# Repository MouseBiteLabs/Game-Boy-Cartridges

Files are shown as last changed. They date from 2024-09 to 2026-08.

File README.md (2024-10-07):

# Game Boy Cartridge Circuit Boards

This is a repository listing all of my Game Boy game circuit board variants.

## Game Boy Board Links

| **Board Name** | **Board Number** | **Max ROM Size** | **Max RAM Size**  | **Multicart Support?** | **Memory Family Used** |
|---|---|---|---|---|---|
| MBC1 (Type B) | GB-4DV4S-01B | 4 MB | 32 KB | No | Type B (29F016, 29F032, 29F033) |
| MBC3 (Type B) | GB-4KV4S-01B | 4 MB | 32 KB | No | Type B (29F016, 29F032, 29F033) |
| MBC5 (Type B) | GB-4AV8S-01B | 4 MB | 128 KB | No | Type B (29F016, 29F032, 29F033) |
| MBC3 Multicart | GB-4KV8S-01B | 4 MB (2x 2 MB, 4x 1MB) | 128 KB (4x 32 KB) | Yes | Type B (29F032, 29F033) |
| MBC5 Multicart | GB-4AV8S-01B | 4 MB (2x 2 MB, 4x 1MB) | 128 KB (4x 32 KB) | Yes | Type B (29F032, 29F033) |
| MBC1 (Type A) | GB-2DV4S-01A | 2 MB | 32 KB | No | Type A (M29F160) |
| MBC3 (Type A) | GB-2KV4S-01A | 2 MB | 32 KB | No | Type A (M29F160) |
| MBC5 (Type A) | GB-2AV8S-01A | 2 MB | 128 KB | No | Type A (M29F160) |
| MBC1 (Type A, FRAM)  | GB-2DF4S-01A | 2 MB | 32 KB | No | Type A (M29F160) |
| MBC3 (Type A, FRAM)  | GB-2KF4S-01A | 2 MB | 32 KB | No | Type A (M29F160) |
| MBC5 (Type A, FRAM)  | GB-2AF4S-01A | 2 MB | 32 KB | No | Type A (M29F160) |

## Naming Convention

| GB | \- | 2 | A | V | 4 | S | \- | 01 | A |
| --- | -- | --- | --- | --- | --- | --- | -- | --- | --- |
| Game Boy | | Max ROM Size (MB) | Mapper Chip | SRAM or FRAM?  | Max RAM Size | Multicart Support | | Revision | Memory Family |
| | | 1 | N = None | X = None | 0 = None | S = Single game | | | A = New EEPROM (M29F160) |
| | | 2 | D = MBC1 | V = SRAM | 1 = 2 KB | D = Multicart (2x, split max ROM/RAM space)  | | | B = NOS EEPROM (29F016, 29F032, 29F033) |
| | | 4 | K = MBC3 | F = FRAM | 2 = 8 KB | Q = Multicart (4x, split max ROM/RAM space)  | | | |
| | | 6 | A = MBC5 | | 4 = 32 KB | | | | |
| | | 8 | | | 8 = 128 KB | | | | |

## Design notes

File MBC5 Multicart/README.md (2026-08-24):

# Game Boy MBC5 Multicart

This is a slightly updated design of my original flashable MBC5-based multicart for the Game Boy. You can make a 2-in-1 or 4-in-1 cartridge, that changes games based on a button press or power cycling the Game Boy. With this board you can also make a single game, but with the addition of a pressable reset button on the cartridge.

**This MBC5 cartridge uses new old stock 29F033 EEPROM chips and battery-backed SRAM.**

The features are as follows:

- Able to make a cartridge with either 2x 2 MB games or 4x 1 MB games
- Adds a pressable button to the cartridge (no shell cutting required)
  - The button can be configured to cycle games on the cart, reset the console, or both
- Configurable to have separate save data for each game, or to share the same save data across multiple games
- Fully compatible with the <a href="https://www.gbxcart.com/">GBxCart RW</a> so you can transfer games and save files to and from the board

Some examples of fun cartridges you can make with this board are:
- A single Pokemon game that has a reset button
- Both Pokemon Red and Blue with separate saves
- Both Pokemon Red and Blue with *the same* save (save files are compatible between versions!)
- Both Pokemon Red and Blue with *the same* save that can switch between versions *during gameplay without resetting* (hotswap!)
- A single copy of Powerpuff Girls with two separate save files



All gerbers and source files can be found in this repo, as this project is fully open source.

## Tutorial Video

This is a video tutorial for the MBC3 multicart specifically, but the process is nearly identical.

Multicart Video Tutorial (http://www.youtube.com/watch?v=DJ7rJUZhDuM "Game Boy Multicart Tutorial (Pokemon Gold and Silver)")

## Important Things Before You Start

1) To use this board, you need to have an original Game Boy game that uses an MBC5 mapper chip. <a href="https://catskull.net/gb-rom-database/">You can find a list of games and their mappers here</a>. Use the search function. Please note the RAM is in bytes, not bits. Since SRAM in this repo is defined in bits, you need to convert by multiplying the number of bytes by 8.
2) You will need to remove the MBC5 from your donor cartridge for use on this board. This will require a hot air rework station or a hot plate. There's a list below of other parts you can re-use from the donor cartridge.
3) When soldering parts on, it's a good idea to put kapton tape or otherwise cover the bottom cartridge edge. You do not want to get solder on the cartridge contacts.
4) I am not responsible for any damage you do to your self or your property. Attempt this project at your own risk.
5) I do not guarantee design compatibility. You may encounter issues with certain games. There is also a chance I have made an error in the design or the BOM - if this is the case, I will do everything I can to address the problem as quickly as possible.
6) If you are using this board to make games other than for personal use, you must have permission from the originator to use and distribute any ROM images or other related material. You are responsible for making sure you adhere to any license requirements.

DO NOT use my circuit boards for profiting from stolen work - this especially includes homebrew content, ROM hacks, and using fan-made labels without permission from the originator. **Support original creators!**

## Board Characteristics and Order Information

The zipped folder contains all the gerber files for this board. The following options **must** be chosen when ordering boards for yourself.

- Thickness: 0.8mm
- Surface Finish: ENIG
- Gold Fingers: Yes, 30° chamfer

You can use the zipped folder at any board fabricator you like. You may also buy the board from PCBWay using this link (disclosure: I receive 10% of the sale value to go twoards future PCB orders of my own):

<a href="https://www.pcbway.com/project/shareproject/Game_Boy_MBC5_Multicart_Updated_3609010b.html">PCB from PCBWay</a>

<a href="https://oshpark.com/shared_projects/IAKoKwEI">The board is also listed on OSH Park as well.</a> **Be sure to get them in 0.8mm thickness if you order from here.**

### Purchase from Etsy

I also offer the board on Etsy, if you would rather purchase through there - click the banner to be redirected.

<a href="https://mousebitelabs.etsy.com/listing/1880161628/game-boy-multicart-pcb-mbc5-v20">PCB from Etsy</a> 

## Required Equipment

The EEPROM on the board needs to be programmed somehow. There are a few options for doing this:

1) <a href="https://www.gbxcart.com/">**GBxCart**</a>. This is a perfect option if you want an easy way to make Game Boy cartridges without a lot of extra effort. This is a standalone flasher that plugs into your computer via USB. The cartridge circuit board is fully compatible with it, and it makes reflashing games extremely easy using <a href="https://github.com/lesserkuma/FlashGBX">lesserkuma's FlashGBX software</a>.
2) At the lowest level, you can buy an EEPROM programmer with a TSOP chip programming adapter. The downside to this method is that you have to desolder the chip every time you want to program it. The <a href="https://flashcatusb.com/">FlashcatUSB</a> is one popular option in retro spaces, but I use the <a href="https://xgecu.myshopify.com/products/xgecu-new-t48-tl866-3gprogrammer-v12-01-support-28000-ics-for-spi-nor-nand-flash-emmc-bga153-162-169-100-221-tsop-sop-plcc">T48 programmer</a> with the <a href="https://xgecu.myshopify.com/products/100-original-xgecu-adp_f48_ex-1-tsop48-special-adapter-for-nor-flash-only-use-on-t48-tl866-3g-programmer">TSOP48 adapter</a>.

You may also be able to use the <a href="https://github.com/sanni/cartreader">**OSCR**</a> by sanni, but in order to do that you will need to prepare a single ROM file with both games and program it to the first game slot. Or, you will need to add a programming routine into the Arduino code to write a file without erasing the chip first. Consider yourself on your own for this until an addition to the OSCR repository is made to address this.

### How to Program the Cartridges

When using the GBxCart to program multiple games to the cartridge, it's recommended to turn SW2A and SW2B (detailed below) to the OFF position. To change ROM/RAM banks to program, simply press the SW1 tactile button between programming steps. Using FlashGBX's "Refresh" button should show that the game information on the left of the screen changes after pressing the button.

If you're programming the flash chip separate from the board, you'll need to concatenate all the ROM files together into one large 4 MB file to program the chip with.

<a href="https://github.com/MouseBiteLabs/Game-Boy-Cartridges/wiki">Also, you can check out the wiki for more information.</a>

## Battery Safety

When assembling a board, I recommend populating all the parts *except* the battery, and getting it to run initially without it. This is to make it easier to fix any solder connections that might need fixing, without having to worry about getting the battery hot. And if you need to rework anything near the battery after you've put it on the board, be safe and remove it before putting a hot soldering iron next to it.

And this should go without saying, but if you're assembling these boards with a hot plate or hot air, *do not* solder the battery on this way. You should use an iron, and keep heat off of the battery as much as possible. 

(Also check polarity!)

## Board Configurations

There's a lot to cover here. There are four separate switches to configure, and two different sizes of SRAM to pick from.

*Note that you can simply solder bridges from the middle pads of the switches to the left or right to the "ON" or "OFF" positions, instead of installing an actual switch.*

### SRAM Size Selection

There are two sizes of SRAM you can use, and the type you use will dictate how your save data is stored on the cartridge and if it's shared between games or not.

- If you use a 1 Mbit SRAM (like the AS6C1008), then each game you put on the cartridge will have its own separate save files. If you program multiple copies of the same game, then you can effectively have multiple save files on the same cart. Easy example is Pokemon games - they only let you have one save file, but if you put Pokemon Red on the multicart four times, then that gives you four separate save files!
- If you use a 256 Kbit SRAM (like the AS6C62256) then all the games you put on the cartridge will *share* the same RAM space.  This feature is probably only useful for Pokemon games. As an example: this means that if you made a cart that has Pokemon Red and Blue on it, you would play both versions with the same save data, as save data between the two games are compatible with each other.

### Game Cycling Mode Switch (SW2)

SW2, split into two separate switches SW2A (top half) and SW2B (bottom half), controls how you change games on the cartridge. The following table describes the different settings:

| Mode | SW2A (Bottom) | SW2B (Top) | Game change with reset? | Game change with button press? | Does the button reset? |
| ---- | --- | --- | --- | --- | --- |
| 1 | OFF | OFF | No | Yes | Yes |
| 2 | OFF | ON | No | Yes | No |
| 3 | ON | OFF | Yes | Yes | Yes |
| 4 | ON | ON | Yes | No | No |

*Note: Mode 4 does not give function to the push button at all.*

The "game change" method in this table describes how you advance down the "game" columns described in the table for SW3.

### Game and Save Data Configuration Switch (SW3)

SW3, split into two separate switches SW3A (bottom half) and SW3B (top half), controls the order in which the ROM banks (the games) and the RAM banks (the save data) cycle. This table assumes you are using a 1 Mbit SRAM chip. If you are using a 256 Kbit SRAM, then every entry in the "RAM Banks" column can be described as "1x 256 Kbit", and all the "Game" columns will share that single RAM bank.

Please note that SW3A and SW3B are *different* than the SW3A and SW3B on the MBC3 Multicart PCB.

| Mode | SW3A (Top) | SW3B (Bottom) | ROM Banks  | RAM Banks | Game 1 | Game 2 | Game 3 | Game 4 |
| ---- | ---- | ---- | --- | --- | --- | --- | --- | --- |
| A | ON | OFF  | 2x 2 MB | 4x 256 Kbit | ROM1, RAM1 | ROM1, RAM2 | ROM2, RAM3 | ROM2, RAM4 |
| B | OFF  | OFF  | 4x 1 MB | 4x 256 Kbit | ROM1, RAM1 | ROM2, RAM2 | ROM3, RAM3 | ROM4, RAM4 |
| C | ON | ON | 2x 2 MB | 2x 256 Kbit | ROM1, RAM1 | ROM2, RAM2 | | |
| D | OFF  | ON | 2x 1 MB | 2x 256 Kbit | ROM1, RAM1 | ROM2, RAM2 | | |

*Note: Mode D is the same as Mode C, but with restricted space for the ROM, so there's no practical use for Mode D.*

### Game Mode Examples

Here's a list of example cartridges you can make with these settings:
1) Pokemon Red, Blue, Yellow, and Green on one cartridge with separate save files that changes only via pressing the button, which also resets the game: **Mode 1B** with 1 Mbit SRAM
2) Pokemon Red and Blue with separate save files that changes by pressing the button *or* cycling power on the Game Boy: **Mode 3C** with 1 Mbit SRAM
3) Pokemon Red and Blue with the same save file that hotswaps when you press the button on the cartridge (changing games during gameplay): **Mode 2C** with 256 Kbit SRAM

## Test Points and Final Checkout

On the back of the board are five test points. Here's where they are connected:

- TP1: SRAM supply voltage
- TP2: Battery voltage (after R1)
- TP3: Battery voltage (positive terminal of battery)
- TP4: Ground
- TP5: VCC input voltage

After you assemble your game, you should measure the current out of the battery. But first, you should program it with the GBxCart, or if you programmed the EEPROM separately, put it into a Game Boy and cycle power once. Then, flip the PCB upside down on a non-conductive surface (not your leg), and set your multimeter in DC millivolts (or volts). Put the positive probe on TP3 and the negative probe on TP2. If you used a 10kΩ for R1, as indicated in the BOM, you should read a voltage in the single or tens of millivolts. If you have something much higher, especially voltages above 100mV, then you likely have an issue or short circuit on the board somewhere.

**Note: You need to power up the game at least once before battery currents will make sense - the battery management ICs can start up in an unknown state before applying main power to the board.**

To estimate battery life, see <a href="https://github.com/MouseBiteLabs/Game-Boy-MBC5-Cartridge/tree/main/Technical#estimating-battery-life">this section in the Technical Design Document of my first MBC5 design</a>, or for more in-depth analysis, <a href="https://hackaday.io/project/11864-tritiled/log/72554-determining-maximum-runtime-176-to-202-years-cr2032">this Hackaday post</a>.

### Battery Size Considerations

The coin cells commonly used on Game Boy carts in order of increasing size are CR2016, CR2025, and CR2032. The CR2032 is the thickest, but yields the longest battery life.

Batteries that are as large as CR2032 will fit inside the shell, *however*, due to the thickness of the CR2032, using one makes it so the shell cannot be pressed down very easily. This makes the button inside the shell difficult to press reliably. For this reason, I recommend using the CR2025. If you want to use a CR2032 for a bit longer battery life, you should only expect to make a cart that changes games via power cycling only (Modes 3 or 4).

I haven't tested it, but I believe using battery holders instead of pre-tabbed batteries will similarly cause issues with trying to press the button in the middle of the cartridge.

## Board Fitment

The shape of this board was originally meant to mimic original Game Boy circuit boards as closely as possible. Unfortunately, when placed in some aftermarket Game Boy cartridge shells (like those from Cloud Game Store), the circuit board has a lot of freedom to rotate around the main screw hole in the bottom-middle of the cartridge. This can cause misalignment when you put it in a Game Boy, which can cause a game to either not load properly (garbled Game Boy logo) or shut off the Game Boy because of a short circuit. This isn't *dangerous* or anything, just annoying.

In order to make the boards fit nicer in any kind of shell, I added extended tabs of circuit board material to the edges of the cartridges to keep it from rotating too much in shells, which was suggested to me by <a href="https://github.com/orangeglo">orangeglo</a>! (Thanks!)

If you're having trouble fitting the circuit board into a shell, because the tabs interfere with the cart edges, you can safely sand or trim them down as there is no copper within the tabs themselves. The only shell that appears to require any kind of trimming are Kitsch-Bent shells.

## Bill of Materials (BOM)

| Reference Designators | Value/Part Number | Package | Description | Source |
| --- | --- | --- | --- | --- |
| B1 | CR2025, CR2016, CR2032*| See note above | Backup Battery | [https://mou.sr/3PLccol](https://mou.sr/3PLccol) |
| C1 | 0.1uF | 0603 | Capacitor (MLCC) | [https://mou.sr/3ENc15O](https://mou.sr/3ENc15O) |
| C4 | 0.1uF | 0603 | Capacitor (MLCC) | [https://mou.sr/3ENc15O](https://mou.sr/3ENc15O) |
| C5 | 0.1uF | 0603 | Capacitor (MLCC) | [https://mou.sr/3ENc15O](https://mou.sr/3ENc15O) |
| C6 | 10uF | 0603 | Capacitor (MLCC) | [https://mou.sr/3mZtSkF](https://mou.sr/3mZtSkF) |
| C7 | 0.1uF | 0603 | Capacitor (MLCC) | [https://mou.sr/3ENc15O](https://mou.sr/3ENc15O) |
| C8 | 0.01uF | 0603 | Capacitor (MLCC) | [https://mou.sr/3AsRwK1](https://mou.sr/3AsRwK1) |
| C12 | 0.1uF | 0603 | Capacitor (MLCC) | [https://mou.sr/3ENc15O](https://mou.sr/3ENc15O) |
| Q1 | 2N7002 | SOT-23 | N-Channel FET | [https://mou.sr/3rgfh6J](https://mou.sr/3rgfh6J) |
| R1 | 10k | 0603 | Resistor | [https://mou.sr/3riR7IH](https://mou.sr/3riR7IH) |
| R5 | 130k | 0603 | Resistor | [https://mou.sr/3MjXliy](https://mou.sr/3MjXliy) |
| R6 | 130k | 0603 | Resistor | [https://mou.sr/3MjXliy](https://mou.sr/3MjXliy) |
| R9 | 130k | 0603 | Resistor | [https://mou.sr/3MjXliy](https://mou.sr/3MjXliy) |
| R10 | 49.9k | 0603 | Resistor | [https://mou.sr/3Q3NRZO](https://mou.sr/3Q3NRZO) |
| SW1 | See note | 5.2 x 5.2mm | Tactile Switch | See Note |
| SW2 | CAS-D20TA | J Form Lead | Dual SPDT | [https://mou.sr/44YZNT5](https://mou.sr/44YZNT5) |
| SW3 | CAS-D20TA | J Form Lead | Dual SPDT | [https://mou.sr/44YZNT5](https://mou.sr/44YZNT5) |
| U1 | 29F032, 29F033 | TSOP-40 | Flash EEPROM | AliExpress or eBay |
| U2 | MBC5 | QFP-32 | MBC5 Mapper | Donor MBC5 Game Boy cartridge |
| U3 | AS6C62256, AS6C1008 | SOP-28, SOP-32 | SRAM | [https://mou.sr/3sFegFF](https://mou.sr/3sFegFF) |
| U4 | TPS3613 | MSOP-10 | Battery Management | [https://mou.sr/45Ir2kh](https://mou.sr/45Ir2kh) |
| U5 | SN74HCS74 | TSSOP-14 | Dual Flip Flop | [https://mou.sr/3QYGEuT](https://mou.sr/3QYGEuT) |
| U6 | SN74AHC1G126 | SC70 | Tri-State Buffer | [https://mou.sr/3T9Zdim](https://mou.sr/3T9Zdim) |
| U7 | SN74AHC1G126 | SC70 | Tri-State Buffer | [https://mou.sr/3T9Zdim](https://mou.sr/3T9Zdim) |
| U8 | SN74AHC1G126 | SC70 | Tri-State Buffer | [https://mou.sr/3T9Zdim](https://mou.sr/3T9Zdim) |

### Note about SW1

If SW1 is long enough, it will sit inside the shell in a way that lets you press it by lightly pressing on the cartridge shell. This way, you can activate it without removing it from the console. You need to find a switch that has an extended stem on AliExpress, eBay, or Amazon (**if you find a compatible switch on Mouser or Digikey, please let me know**). The measurements will be 5.2 mm x 5.2 mm, with a height of 3.5 mm. Sometimes these parts are listed as "4 mm x 4 mm" or "5 mm x 5 mm" instead. Check the datasheet, if available, to see if it'll fit the footprint. They should have listing pictures similar to the ones seen here:



### Note about SW2, SW3

Instead of using the somewhat pricey switch designated for SW2 and SW3, you can instead just bridge the pads with solder from the middle pad to the pad in the direction you want to set the switch to. For example - in the below picture, SW3A and SW3B are both in the "ON" position in both cases. (Note that the white switches on the right image are switched to the right.)



### Usable Donor Cartridge Parts

You can use a few parts from the donor cart on the new board to save some money. Note that you will generally get better reliability with new parts as opposed to old ones. For example: I have seen failed RAM chips from donors in the past.

1) **U2: MBC5** - This one is required
2) **U3: SRAM** - You can use this part *only if* the sum of the RAM space for the games you're using is the same or less amount of RAM that the donor cartridge has. If you plan to have separate save data for every game, you'll probably need to buy an AS6C1008.

You could probably transfer over most of the 0.1uF capacitors but they're pretty cheap anyway, so I generally just recommend buying new resistors and capacitors.

## Things to Remember

- The 29F032 and 29F033 have been known to occasionally be defective upon arrival. They're either used, or new old stock, and usually only available from AliExpress.
- The footprint for the battery can fit a CR2032, CR2025, or CR2016 with solder tabs. The only difference is the mAh capacity (larger number = longer life). If you get Panasonic tabbed batteries, you may have to trim the battery tabs to make them fit on the footprint.
- Generally, ROM sizes are conveyed in terms of kilobytes and megabytes (KB, MB). RAM size is usually conveyed in terms of kilobits or megabits (Kbit, Mbit). You can convert Kbit and Mbit to KB and MB by dividing Kbit or Mbit by 8. For example, 256 Kbit = 32 KB.

## Labels

If you want a Bucket Mouse branded label for your cartridge, look no further than <a href="https://krizdingus.com/mousebitelabs/">krizdingus's designs</a>. Special thanks to Kris for designing these, they look awesome! (If you are going to order/print these, use the high-res images hosted on his website, and *keep the labels for personal or non-commercial use only.*)



## Why not FRAM?

This particular board is designed for using low retention power SRAM, or Static RAM. One downside to SRAM is that you need a battery to keep the SRAM powered on even when the game is turned off if you want to retain the data on the chip. So eventually the battery will die, and your save data will be lost.

The other popular option for holding save data is using FRAM, or Ferroelectric RAM, to keep save data around even after the battery dies (specifically, the popular part that's used for Game Boy FRAM carts is the FM18W08).

So, why would anyone ever use SRAM over FRAM if FRAM doesn't need a battery? Well, they do come with a number of downsides:

1) Quality, new stock, 5V tolerant FRAM is expensive ($12+ per part).
2) Cheaper FRAM chips from eBay or Aliexpress are notoriously flaky (anecdotally, ~50% success rate).
3) **FM18W08 maxes out at 256K (which is restrictive for multicarts).**
4) FRAM memory access requires different chip select timing than SRAM, and the Game Boy expects SRAM, so it is not natively compatible with FRAM carts. The Gameboy Color specifically cannot (easily) be made to properly access FM18W08 chip. You *can* use an OR gate and add the CLK on the cart edge to try to achieve the necessary timing, but it only works (properly) for DMG/MGB/SGB, not the GBC. It usually *works* in practice for GBC, but it's technically a datasheet violation and can potentially cause issues in edge cases. <a href="https://github.com/Gekkio">(Thanks to gekkio for pointing this out!)</a>

In contrast, *brand new* quality SRAM chips are ~$3, and you can even save that by using the original SRAM from a donor cartridge if you want to. You will easily get more than a decade of life running on a battery. You're already assembling this cartridge; you can dump the save and replace the battery before then.

## Revision History

### v2.1
- Removed triangle on silkscreen from U8

### v2.0
- Fixed issue with previous design where SW2A being in the ON position caused excess save battery drain
- Added board number to the top of the board
- Updated silkscreen and cartridge style to match my other Game Boy cartridges
- Removed R8, made EEPROM writable via the /WR pin on the cart edge

### v1.3
- Fixed debounce circuit for push button
- Adjusted board edge tabs to better fit in shells

### v1.2
- Added nubs on the board edge to prevent the circuit board from rattling around in aftermarket cartridges

### v1.1
- Fix schematic errors
- Extended cart edge down by 0.25 mm for better fitment
- Added OSHW logo and "SUPPORT ORIGINAL CREATORS!"

### v1.0
- Prototype revision

## Resources and Acknowledgements

- <a href="http://www.devrs.com/gb/files/hardware.html">Jeff Frohwein's GameBoy Tech Page</a>
- <a href="https://gbhwdb.gekkio.fi/">Game Boy Hardware Database</a>
- <a href="https://catskull.net/gb-rom-database/">Nintendo Gameboy Game List</a>
- <a href="https://www.gbxcart.com/">insideGadgets discord server for GBxCart RW compatibility requirements</a>
- <a href="https://github.com/lesserkuma/FlashGBX">Lesserkuma's FlashGBX software</a>
- <a href="https://www.ti.com/lit/ds/symlink/tps3613-01.pdf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">TPS3613 Datasheet</a>
- Board outline modified from <a href="https://tinkerer.us/projects/homebrew-gameboy-cartridge.html">Dillon Nichols's Homebrew Gameboy Cartridge project</a>
- Thanks to <a href="https://github.com/orangeglo">orangeglo</a> for his suggestion of adding spacers around the board edge for better fitment in aftermarket cartridges
- Some components from <a href="https://github.com/adafruit/Adafruit-Eagle-Library">Adafruit's Eagle parts library</a>
- Some components from <a href="https://www.snapeda.com/">SnapMagic</a>
- Thank you to <a href="https://github.com/Gekkio">gekkio</a> for their deep Game Boy knowledge resources, and for collaboration in demystifying some of the design choices on Game Boy cartridges

## License

<br />This work is licensed under a <a rel="license" href="http://creativecommons.org/licenses/by-sa/4.0/">Creative Commons Attribution-ShareAlike 4.0 International License</a>. You are able to copy and redistribute the material in any medium or format, as well as remix, transform, or build upon the material for any purpose (even commercial) - but you **must** give appropriate credit, provide a link to the license, and indicate if any changes were made.

©MouseBiteLabs 2025

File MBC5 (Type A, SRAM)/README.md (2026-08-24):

# Game Boy MBC5 Cartridge - Type A, SRAM

This is an updated design of my flashable MBC5-based cartridge for the Game Boy. The MBC5 mapper greatly augments the memory access of the Game Boy for larger games. Most of the games that came out in the last years of the Game Boy and Game Boy Color used the MBC5 mapper.

**This MBC5 cartridge uses brand new M29F160 EEPROM chips and battery-backed SRAM.**

This circuit board should cover most MBC5 games. The features are as follows:

- Able to make games up to 2 MB in size, that use up to 1 Mbit of RAM
- Compatibility with all four of the popular Game Boy battery management ICs - MM1026, MM1134, BA6129, and BA6735
- The option to add battery backup to the cartridge *without* the need of the original battery management ICs - perfect for MBC5 donors that didn't have batteries in them
- Fully compatible with both the <a href="https://www.gbxcart.com/">GBxCart RW</a> and sanni's <a href="https://github.com/sanni/cartreader">Open Source Cart Reader (OSCR)</a> so you can transfer games and save files to and from the board



All gerbers and source files can be found in this repo, as this project is fully open source **with attribution.**

## Important Things Before You Start

1) To use this board, you need to have an original Game Boy game that uses an MBC5 mapper chip. <a href="https://catskull.net/gb-rom-database/">You can find a list of games and their mappers here</a>. Use the search function. Please note the RAM is in bytes, not bits. Since RAM in this repo is defined in bits, you need to convert by multiplying the number of bytes by 8.
2) You will need to remove the MBC5 from your donor cartridge for use on this board. This will require a hot air rework station or a hot plate. There's a list below of other parts you can re-use from the donor cartridge.
3) When soldering parts on, it's a good idea to put kapton tape or otherwise cover the bottom cartridge edge. You do not want to get solder on the cartridge contacts.
4) I am not responsible for any damage you do to your self or your property. Attempt this project at your own risk.
5) I do not guarantee design compatibility. You may encounter issues with certain games. There is also a chance I have made an error in the design or the BOM - if this is the case, I will do everything I can to address the problem as quickly as possible.
6) If you are using this board to make games other than for personal use, you must have permission from the originator to use and distribute any ROM images or other related material. You are responsible for making sure you adhere to any license requirements.

DO NOT use my circuit boards for profiting from stolen work - this especially includes homebrew content, ROM hacks, and using fan-made labels without permission from the originator. **Support original creators!**

## Board Characteristics and Order Information

The zipped folder contains all the gerber files for this board. The following options **must** be chosen when ordering boards for yourself.

- Thickness: 0.8mm
- Surface Finish: ENIG
- Gold Fingers: Yes, 30° chamfer

You can use the zipped folder at any board fabricator you like. You may also buy the board from PCBWay using this link (disclosure: I receive 10% of the sale value to go towards future PCB orders of my own):

<a href="https://www.pcbway.com/project/shareproject/Game_Boy_MBC5_Cartridge_M29F160_SRAM_85a95874.html">PCB from PCBWay</a>

<a href="https://oshpark.com/shared_projects/Gdh9uAeD">The board is also listed on OSH Park as well.</a> **Be sure to get them in 0.8mm thickness if you order from here.**

### Purchase from My Website

You can purchase this circuit board at my website, [https://mousebitelabs.store](https://mousebitelabs.store). Click the following image to be directed to the specific item listing:

<a href="https://mousebitelabs.store/products/game-boy-mbc5-flash-cartridge-circuit-board">PCB from MouseBiteLabs</a>

### Purchase from Etsy

I also offer the board on Etsy, if you would rather purchase through there - click the banner to be redirected.

<a href="https://mousebitelabs.etsy.com/listing/1894341187/game-boy-cartridge-pcb-mbc5-type-a">PCB from Etsy</a> 

## Required Equipment

The EEPROM on the board needs to be programmed somehow. There are a few options for doing this:

1) <a href="https://www.gbxcart.com/">**GBxCart**</a>. This is a perfect option if you want an easy way to make Game Boy cartridges without a lot of extra effort. This is a standalone flasher that plugs into your computer via USB. The cartridge circuit board is fully compatible with it, and it makes reflashing games extremely easy using <a href="https://github.com/lesserkuma/FlashGBX">lesserkuma's FlashGBX software</a>.
2) <a href="https://github.com/sanni/cartreader">**OSCR**</a> by sanni. This is the Open Source Cart Reader, capable of making backups of both the ROM and RAM contents of cartridges across many different systems - like the NES, SNES, Genesis, and of course Game Boy and Game Boy Advance. And you can also use it to flash these Game Boy cartridges. The OSCR however requires assembly (or someone to assemble it for you) and is a bit more cumbersome to interface with on a PC, but it's an extremely powerful tool that I can't recommend enough if you want to expand past Game Boys.
3) At the lowest level, you can buy an EEPROM programmer with a TSOP chip programming adapter. The downside to this method is that you have to desolder the chip every time you want to program it. The <a href="https://flashcatusb.com/">FlashcatUSB</a> is one popular option in retro spaces, but I use the <a href="https://xgecu.myshopify.com/products/xgecu-new-t48-tl866-3gprogrammer-v12-01-support-28000-ics-for-spi-nor-nand-flash-emmc-bga153-162-169-100-221-tsop-sop-plcc">T48 programmer</a> with the <a href="https://xgecu.myshopify.com/products/100-original-xgecu-adp_f48_ex-1-tsop48-special-adapter-for-nor-flash-only-use-on-t48-tl866-3g-programmer">TSOP48 adapter</a>.

### How to Program the Cartridges

<a href="https://github.com/MouseBiteLabs/Game-Boy-Cartridges/wiki">Check out the wiki for more information.</a>

## Battery Safety

When assembling a board, I recommend populating all the parts *except* the battery, and getting it to run initially without it. This is to make it easier to fix any solder connections that might need fixing, without having to worry about getting the battery hot. And if you need to rework anything near the battery after you've put it on the board, be safe and remove it before putting a hot soldering iron next to it.

If you're assembling these boards with a hot plate or hot air, *do not* solder the battery on this way. You should use an iron, and keep heat off of the battery as much as possible. 

(Also check polarity!)

## Board Configurations

The board comes with three sets of jumper pads for solder bridges. SJ1 and SJ2 require you to solder bridge the middle pad either to the left or right pads. SJ3 is configured by either leaving the pads unsoldered or bridging them with solder. Here are the situations where you need to add solder bridges.

**<a href="https://github.com/MouseBiteLabs/Game-Boy-Cartridges/wiki/MBC5">You can check out the wiki for some pictures of boards in various configurations to follow along with.</a>**

### RAM Size Selection (SJ1 and SJ2, or SW1)

These jumpers are located underneath the MBC5 chip, and labeled "64K" and "256K/1M". Solder them to configure the amount of RAM your cart uses. You must configure these pads for every game you make, unless you do not need RAM. <a href="https://catskull.net/gb-rom-database/">You can find a list of games here with their respective RAM sizes.</a>

- If the game you're making uses 256 Kbit or 1 Mbit of RAM, then solder the middle pads of the two jumper sets to the right pads.
- If the game you're making uses 64 Kbit of RAM, then solder the middle pads of the two jumper sets to the left pads.
- SJ1 and SJ2 must be soldered in the same direction.
- The footprint of these selection pads should allow for a DPDT switch, part number CAS-220A1, to be placed on these pads instead of having to bridge the pads with solder.



Note that you can make games that only require 64 Kbit of RAM and still use a 256 Kbit or 1 Mbit SRAM chip. You still need to configure the jumpers to the 64Kb setting, though.

**I recommend using 64 Kbit or 256 Kbit RAM chips, unless you absolutely need 1 Mbit for the game you are making.**

### Using an MM1134 or BA6735 for U4 (SJ3)

Bridge the jumper SJ3 if you have either an MM1134 or BA6735 for U4, specifically. Any other battery management IC must leave SJ3 unsoldered.

## Test Points and Final Checkout

On the back of the board are five test points. Here's where they are connected:

- TP1: SRAM supply voltage
- TP2: Battery voltage (after R1)
- TP3: Battery voltage (positive terminal of battery)
- TP4: Ground
- TP5: VCC input voltage

After you assemble your game, you should measure the current out of the battery. But first, you should program it with the GBxCart or the OSCR, or if you programmed the EEPROM separately, put it into a Game Boy and cycle power once. Then, flip the PCB upside down on a non-conductive surface (not your leg), and set your multimeter in DC millivolts (or volts). Put the positive probe on TP3 and the negative probe on TP2. If you used a 10kΩ for R1, as indicated in the BOM, you should read a voltage in the single of millivolts. If you have something much higher, especially voltages above 20mV, then you likely have an issue or short circuit on the board somewhere.

**Note: You need to power up the game at least once before battery currents will make sense - the battery management ICs can start up in an unknown state before applying main power to the board.**

To estimate battery life, see <a href="https://github.com/MouseBiteLabs/Game-Boy-MBC5-Cartridge/tree/main/Technical#estimating-battery-life">this section in the Technical Design Document of my first MBC5 design</a>, or for more in-depth analysis, <a href="https://hackaday.io/project/11864-tritiled/log/72554-determining-maximum-runtime-176-to-202-years-cr2032">this Hackaday post</a>.

## Board Fitment

The shape of this board was originally meant to mimic original Game Boy circuit boards as closely as possible. Unfortunately, when placed in some aftermarket Game Boy cartridge shells (like those from Cloud Game Store), the circuit board has a lot of freedom to rotate around the main screw hole in the bottom-middle of the cartridge. This can cause misalignment when you put it in a Game Boy, which can cause a game to either not load properly (garbled Game Boy logo) or shut off the Game Boy because of a short circuit. This isn't *dangerous* or anything, just annoying.

In order to make the boards fit nicer in any kind of shell, I added extended tabs of circuit board material to the edges of the cartridges to keep it from rotating too much in shells, which was suggested to me by <a href="https://github.com/orangeglo">orangeglo</a>! (Thanks!)

If you're having trouble fitting the circuit board into a shell, because the tabs interfere with the cart edges, you can safely sand or trim them down as there is no copper within the tabs themselves. The only shell that appears to require any kind of trimming are Kitsch-Bent shells.

## Bill of Materials (BOM)

Your parts list will vary depending on the game you are trying to make, and what chips you have for the battery management (if any). **You cannot use both U4 and U5 - you must choose one or the other.** U4 comes from a donor cartridge, and U5 is a readily available aftermarket option.

Please carefully review the parts you need for the board you are trying to make. Do not add any parts to your build that don't appear in the column for the game you are making. This means you *cannot* populate every component on the board at the same time.

| Reference Designators | Value/Part Number | Package | Description | No save carts | Save carts with MM1134 or BA6735 | Save carts with MM1026 or BA6129 | Save carts without donor U4 chip | Source |
| --- | --- | --- | --- | --- | --- | --- | --- | --- |
| B1 | CR2032, CR2025, CR2016 | CR2032 | Backup Battery | | X | X | X | [https://mou.sr/3SeAzfT](https://mou.sr/3SeAzfT) |
| C1 | 0.1uF | 0603 | Capacitor (MLCC) | X | X | X | X | [https://mou.sr/3ENc15O](https://mou.sr/3ENc15O) |
| C4 | 0.1uF | 0603 | Capacitor (MLCC) | X | X | x | | [https://mou.sr/3ENc15O](https://mou.sr/3ENc15O) |
| C5 | 0.1uF | 0603 | Capacitor (MLCC) | | X | X | X | [https://mou.sr/3ENc15O](https://mou.sr/3ENc15O) |
| C6 | 10uF | 0603 | Capacitor (MLCC) | | X | X | X | [https://mou.sr/3mZtSkF](https://mou.sr/3mZtSkF) |
| C7 | 0.1uF | 0603 | Capacitor (MLCC) | X | X | X | X | [https://mou.sr/3ENc15O](https://mou.sr/3ENc15O) |
| C8 | 0.1uF | 0603 | Capacitor (MLCC) | | | | X | [https://mou.sr/3ENc15O](https://mou.sr/3ENc15O) |
| Q1 | 2N7002 | SOT-23 | N-Channel FET | | | | X | [https://mou.sr/3rgfh6J](https://mou.sr/3rgfh6J) |
| Q2 | 2N7002 | SOT-23 | N-Channel FET | | | X | | [https://mou.sr/3rgfh6J](https://mou.sr/3rgfh6J) |
| R1 | 10k | 0603 | Resistor | | X | X | X | [https://mou.sr/3riR7IH](https://mou.sr/3riR7IH) |
| R7 | 10k | 0603 | Resistor | | | X | | [https://mou.sr/3riR7IH](https://mou.sr/3riR7IH) |
| R9 | 130k | 0603 | Resistor | | | | X | [https://mou.sr/3MjXliy](https://mou.sr/3MjXliy) |
| R10 | 49.9k | 0603 | Resistor | | | | X | [https://mou.sr/3Q3NRZO](https://mou.sr/3Q3NRZO) |
| U1 | M29F160 | TSOP-48 | Flash EEPROM | X | X | X | X | [https://mou.sr/3N0a9eL](https://mou.sr/3N0a9eL) |
| U2 | MBC5 | QFP-32 | MBC5 Mapper | X | X | X | X | Donor MBC5 Game Boy cartridge |
| U3 | AS6C6264, AS6C62256, AS6C1008  | SOP-28, SOP-32 | SRAM | | X | X | X | [https://mou.sr/3ZxG6jd](https://mou.sr/3ZxG6jd) |
| U4 | MM1026, MM1134, BA6129, BA6735 | SOIC-8 | Battery Management | | X | X | | Donor Game Boy cartridge |
| U5 | TPS3613 | MSOP-10 | Battery Management | | | | X | [https://mou.sr/45Ir2kh](https://mou.sr/45Ir2kh) |

*Note that C9 - C11 footprints are only included on the board for strange edge cases that may require them sometime in the future; do not populate! See the technical design document for more information.*

### Usable Donor Cartridge Parts

You can use a few parts from the donor cart on the new board to save some money. Note that you will generally get better reliability with new parts as opposed to old ones. For example: I have seen failed RAM chips from donors in the past.

1) **U2: MBC5** - This one is required
2) **U3: SRAM** - You can use this part *only if* the game you're making uses the same or less amount of RAM that the donor cartridge does
3) **U4: Battery Management IC** - Using this is probably preferred over the TPS3613 because it'll save you money and parts to put on

You could probably transfer over most of the 0.1uF capacitors but they're pretty cheap anyway, so I generally just recommend buying new resistors and capacitors.

## Things to Remember

- The footprint for the battery can fit a CR2032, CR2025, or CR2016 with solder tabs. The only difference is the mAh capacity (larger number = longer life). If you get Panasonic tabbed batteries, you may have to trim the battery tabs to make them fit on the footprint.
  - For untabbed coin cells, you can find battery retainer adapters online, <a href="https://retrogamerepairshop.com/products/hdr-game-boy-game-battery-retainer?variant=40511013290156">like this one</a>.
- For battery management, use either U4 *or* U5 and supporting components. **Do not** use U4 and U5 simultaneously on one board. They will interfere with each other.
- Generally, ROM sizes are conveyed in terms of kilo**bytes** and mega**bytes** (KB, MB). RAM size is usually conveyed in terms of kilo**bits** or mega**bits** (Kbit, Mbit). You can convert Kbit and Mbit to KB and MB by dividing Kbit or Mbit by 8. For example, 256 Kbit = 32 KB.
- You only need to provide ROM and RAM chips that have at least *or greater* the size of the game you are trying to make. That means you can use a 256 Kbit SRAM chip for a game that only requires 64 Kbit of RAM!

## Labels

If you want a Bucket Mouse branded label for your cartridge, look no further than <a href="https://krizdingus.com/mousebitelabs/">krizdingus's designs</a>. Special thanks to Kris for designing these, they look awesome! (If you are going to order/print these, use the high-res images hosted on his website, and *keep the labels for personal or non-commercial use only.*)



## Why Not FRAM?

This particular board is designed for using low retention power SRAM, or Static RAM. One downside to SRAM is that you need a battery to keep the SRAM powered on even when the game is turned off if you want to retain the data on the chip. So eventually the battery will die, and your save data will be lost.

The other popular option for holding save data is using FRAM, or Ferroelectric RAM, to keep save data around even after the battery dies (specifically, the popular part that's used for Game Boy FRAM carts is the FM18W08).

So, why would anyone ever use SRAM over FRAM if FRAM doesn't need a battery? Well, they do come with a number of downsides:

1) Quality, new stock, 5V tolerant FRAM is expensive ($12+ per part at the time of writing).
2) Cheaper FRAM chips from eBay or Aliexpress are notoriously flaky (anecdotally, ~50% success rate).
3) FRAM memory access requires different chip select timing than SRAM, and the Game Boy expects SRAM, so it is not natively compatible with FRAM carts. The Gameboy Color specifically cannot (easily) be made to properly access FM18W08 chip. You *can* use an OR gate and add the CLK on the cart edge to try to achieve the necessary timing, but it only works (properly) for DMG/MGB/SGB, not the GBC. It usually *works* in practice for GBC, but it's technically a datasheet violation and can potentially cause issues in edge cases. <a href="https://github.com/Gekkio">(Thanks to gekkio for pointing this out!)</a>

In contrast, *brand new* quality SRAM chips are ~$3, and you can even save that by using the original SRAM from a donor cartridge if you want to. You will *easily* get more than a decade of life running on a battery. You're already assembling this cartridge; you can dump the save and replace the battery before then.

<a href="https://github.com/MouseBiteLabs/Game-Boy-Cartridges/tree/main/MBC5%20(Type%20A%2C%20FRAM)">I do have an FRAM-enabled version of this cartridge,</a> if you're so inclined. They definitely have their place and their benefits. But I personally prefer the SRAM design because I refuse to use AliExpress FRAM chips, and don't want to add a big cost with new FRAM.

## Revision History

### v1.2
- Fix board number

### v1.1
- Update silkscreen style to match other boards
- Add board number to board copper

### v1.0
- Initial revision

## Resources and Acknowledgements

- <a href="http://www.devrs.com/gb/files/hardware.html">Jeff Frohwein's GameBoy Tech Page</a>
- <a href="https://gbhwdb.gekkio.fi/">Game Boy Hardware Database</a>
- <a href="https://catskull.net/gb-rom-database/">Nintendo Gameboy Game List</a>
- <a href="https://www.gbxcart.com/">insideGadgets discord server for GBxCart RW compatibility requirements</a>
- <a href="https://github.com/lesserkuma/FlashGBX">Lesserkuma's FlashGBX software</a>
- <a href="https://github.com/sanni/cartreader">sanni's Open Source Cart Reader (OSCR)</a>, and thanks to the OSCR discord server for help and feedback
- <a href="https://www.alldatasheet.com/datasheet-pdf/pdf/99104/MITSUBISHI/MM1026.html">System Reset IC Datasheet</a>
- <a href="https://www.ti.com/lit/ds/symlink/tps3613-01.pdf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">TPS3613 Datasheet</a>
- Board outline modified from <a href="https://tinkerer.us/projects/homebrew-gameboy-cartridge.html">Dillon Nichols's Homebrew Gameboy Cartridge project</a>
- Thanks to <a href="https://github.com/orangeglo">orangeglo</a> for his suggestion of adding spacers around the board edge for better fitment in aftermarket cartridges
- Some components from <a href="https://github.com/adafruit/Adafruit-Eagle-Library">Adafruit's Eagle parts library</a>
- Some components from <a href="https://www.snapeda.com/">SnapMagic</a>
- Thank you to <a href="https://github.com/Gekkio">gekkio</a> for their deep Game Boy knowledge resources, and for collaboration in demystifying some of the design choices on Game Boy cartridges

## License

<br />This work is licensed under a <a rel="license" href="http://creativecommons.org/licenses/by-sa/4.0/">Creative Commons Attribution-ShareAlike 4.0 International License</a>. You are able to copy and redistribute the material in any medium or format, as well as remix, transform, or build upon the material for any purpose (even commercial) - but you **must** give appropriate credit, provide a link to the license, and indicate if any changes were made.

©MouseBiteLabs 2025

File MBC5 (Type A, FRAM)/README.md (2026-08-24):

# Game Boy MBC5 Cartridge - Type A, FRAM

This is an alternate design of my <a href="https://github.com/MouseBiteLabs/Game-Boy-Cartridges/tree/main/MBC5%20(Type%20A%2C%20SRAM)">flashable MBC5-based cartridge for the Game Boy</a>. This board uses non-volatile FRAM instead of SRAM to hold save data. I made this specifically for use with the <a href="https://github.com/MouseBiteLabs/Super-Game-Boy-Plus/tree/main">Super Game Boy Plus boards.</a>

**This MBC5 cartridge uses brand new M29F160 EEPROM chips and non-volatile FRAM.**

This circuit board should cover most MBC5 games, and is able to make games up to 2 MB in size, that use up to 256 Kbit of RAM. It is fully compatible with both the <a href="https://www.gbxcart.com/">GBxCart RW</a> and sanni's <a href="https://github.com/sanni/cartreader">Open Source Cart Reader (OSCR)</a> so you can transfer games and save files to and from the board. Because of the FRAM this board utilizes, <a href="https://github.com/MouseBiteLabs/Game-Boy-Cartridges/tree/main/MBC5%20(Type%20A%2C%20SRAM)#why-not-fram">it is technically only fully compatible with regular Game Boy games, and not Game Boy Color games,</a> though no issues have been reported in the past when using them with Game Boy Color games.



All gerbers and source files can be found in this repo, as this project is fully open source.

## Important Things Before You Start

1) To use this board, you need to have an original Game Boy game that uses an MBC5 mapper chip. <a href="https://catskull.net/gb-rom-database/">You can find a list of games and their mappers here</a>. Use the search function. Please note the RAM is in bytes, not bits. Since RAM in this repo is defined in bits, you need to convert by multiplying the number of bytes by 8.
2) You will need to remove the MBC5 from your donor cartridge for use on this board. This will require a hot air rework station or a hot plate. There's a list below of other parts you can re-use from the donor cartridge.
3) When soldering parts on, it's a good idea to put kapton tape or otherwise cover the bottom cartridge edge. You do not want to get solder on the cartridge contacts.
4) I am not responsible for any damage you do to your self or your property. Attempt this project at your own risk.
5) I do not guarantee design compatibility. You may encounter issues with certain games. There is also a chance I have made an error in the design or the BOM - if this is the case, I will do everything I can to address the problem as quickly as possible.
6) If you are using this board to make games other than for personal use, you must have permission from the originator to use and distribute any ROM images or other related material. You are responsible for making sure you adhere to any license requirements.

DO NOT use my circuit boards for profiting from stolen work - this especially includes homebrew content, ROM hacks, and using fan-made labels without permission from the originator. **Support original creators!**

## Board Characteristics and Order Information

The zipped folder contains all the gerber files for this board. The following options **must** be chosen when ordering boards for yourself.

- Thickness: 0.8mm
- Surface Finish: ENIG
- Gold Fingers: Yes, 30° chamfer

You can use the zipped folder at any board fabricator you like. You may also buy the board from PCBWay using this link (disclosure: I receive 10% of the sale value to go towards future PCB orders of my own):

<a href="https://www.pcbway.com/project/shareproject/Game_Boy_MBC5_Cartridge_Type_A_FRAM_8dda45ae.html">PCB from PCBWay</a>

<a href="https://oshpark.com/shared_projects/4iVMHuUe">The board is also listed on OSH Park as well.</a> **Be sure to get them in 0.8mm thickness if you order from here.**

## Required Equipment

The EEPROM on the board needs to be programmed somehow. There are a few options for doing this:

1) <a href="https://www.gbxcart.com/">**GBxCart**</a>. This is a perfect option if you want an easy way to make Game Boy cartridges without a lot of extra effort. This is a standalone flasher that plugs into your computer via USB. The cartridge circuit board is fully compatible with it, and it makes reflashing games extremely easy using <a href="https://github.com/lesserkuma/FlashGBX">lesserkuma's FlashGBX software</a>.
2) <a href="https://github.com/sanni/cartreader">**OSCR**</a> by sanni. This is the Open Source Cart Reader, capable of making backups of both the ROM and RAM contents of cartridges across many different systems - like the NES, SNES, Genesis, and of course Game Boy and Game Boy Advance. And you can also use it to flash these Game Boy cartridges. The OSCR however requires assembly (or someone to assemble it for you) and is a bit more cumbersome to interface with on a PC, but it's an extremely powerful tool that I can't recommend enough if you want to expand past Game Boys.
3) At the lowest level, you can buy an EEPROM programmer with a TSOP chip programming adapter. The downside to this method is that you have to desolder the chip every time you want to program it. The <a href="https://flashcatusb.com/">FlashcatUSB</a> is one popular option in retro spaces, but I use the <a href="https://xgecu.myshopify.com/products/xgecu-new-t48-tl866-3gprogrammer-v12-01-support-28000-ics-for-spi-nor-nand-flash-emmc-bga153-162-169-100-221-tsop-sop-plcc">T48 programmer</a> with the <a href="https://xgecu.myshopify.com/products/100-original-xgecu-adp_f48_ex-1-tsop48-special-adapter-for-nor-flash-only-use-on-t48-tl866-3g-programmer">TSOP48 adapter</a>.

### How to Program the Cartridges

<a href="https://github.com/MouseBiteLabs/Game-Boy-Cartridges/wiki">Check out the wiki for more information.</a>

## Board Fitment

The shape of this board was originally meant to mimic original Game Boy circuit boards as closely as possible. Unfortunately, when placed in some aftermarket Game Boy cartridge shells (like those from Cloud Game Store), the circuit board has a lot of freedom to rotate around the main screw hole in the bottom-middle of the cartridge. This can cause misalignment when you put it in a Game Boy, which can cause a game to either not load properly (garbled Game Boy logo) or shut off the Game Boy because of a short circuit. This isn't *dangerous* or anything, just annoying.

In order to make the boards fit nicer in any kind of shell, I added extended tabs of circuit board material to the edges of the cartridges to keep it from rotating too much in shells, which was suggested to me by <a href="https://github.com/orangeglo">orangeglo</a>! (Thanks!)

If you're having trouble fitting the circuit board into a shell, because the tabs interfere with the cart edges, you can safely sand or trim them down as there is no copper within the tabs themselves. The only shell that appears to require any kind of trimming are Kitsch-Bent shells.

## Bill of Materials (BOM)

| Reference | Value/Part Number | Package | Description | Source |
| --- | --- | --- | --- | --- |
| C19 | 0.1u | 0603 | Capacitor (MLCC) | [https://mou.sr/3ENc15O](https://mou.sr/3ENc15O) |
| C20 | 0.1u | 0603 | Capacitor (MLCC) | [https://mou.sr/3ENc15O](https://mou.sr/3ENc15O) |
| C21 | 0.1u | 0603 | Capacitor (MLCC) | [https://mou.sr/3ENc15O](https://mou.sr/3ENc15O) |
| C22 | 0.1u | 0603 | Capacitor (MLCC) | [https://mou.sr/3ENc15O](https://mou.sr/3ENc15O) |
| R17 | 10k | 0603 | Resistor | [https://mou.sr/3riR7IH](https://mou.sr/3riR7IH) |
| U7 | M29F160 | TSOP-48 | Flash EEPROM | [https://mou.sr/3MNWQ0b](https://mou.sr/3MNWQ0b) |
| U8 | MBC5 | QFP-32  | MBC5 Mapper | Donor Game Boy Game |
| U9 | FM18W08-SG | SOIC-28 | FRAM | [https://mou.sr/4cRIJlb](https://mou.sr/4cRIJlb) |
| U10 | SN74LVC1G332 | SOT-363 | 3-input Or Gate  | [https://mou.sr/3XdbXoN](https://mou.sr/3XdbXoN) |

## Labels

If you want a Bucket Mouse branded label for your cartridge, look no further than <a href="https://krizdingus.com/mousebitelabs/">krizdingus's designs</a>. Special thanks to Kris for designing these, they look awesome! (If you are going to order/print these, use the high-res images hosted on his website, and *keep the labels for personal or non-commercial use only.*)



## Revision History

### v1.1
- Fix board number and update silkscreen for consistency

### v1.0
- Initial revision

## Resources and Acknowledgements

- <a href="http://www.devrs.com/gb/files/hardware.html">Jeff Frohwein's GameBoy Tech Page</a>
- <a href="https://gbhwdb.gekkio.fi/">Game Boy Hardware Database</a>
- <a href="https://catskull.net/gb-rom-database/">Nintendo Gameboy Game List</a>
- <a href="https://www.gbxcart.com/">insideGadgets discord server for GBxCart RW compatibility requirements</a>
- <a href="https://github.com/lesserkuma/FlashGBX">Lesserkuma's FlashGBX software</a>
- <a href="https://github.com/sanni/cartreader">sanni's Open Source Cart Reader (OSCR)</a>, and thanks to the OSCR discord server for help and feedback
- Board outline modified from <a href="https://tinkerer.us/projects/homebrew-gameboy-cartridge.html">Dillon Nichols's Homebrew Gameboy Cartridge project</a>
- Thanks to <a href="https://github.com/orangeglo">orangeglo</a> for his suggestion of adding spacers around the board edge for better fitment in aftermarket cartridges
- Some components from <a href="https://github.com/adafruit/Adafruit-Eagle-Library">Adafruit's Eagle parts library</a>
- Some components from <a href="https://www.snapeda.com/">SnapMagic</a>
- Thank you to <a href="https://github.com/Gekkio">gekkio</a> for their deep Game Boy knowledge resources, and for collaboration in demystifying some of the design choices on Game Boy cartridges

## License

<br />This work is licensed under a <a rel="license" href="http://creativecommons.org/licenses/by-sa/4.0/">Creative Commons Attribution-ShareAlike 4.0 International License</a>. You are able to copy and redistribute the material in any medium or format, as well as remix, transform, or build upon the material for any purpose (even commercial) - but you **must** give appropriate credit, provide a link to the license, and indicate if any changes were made.

©MouseBiteLabs 2025

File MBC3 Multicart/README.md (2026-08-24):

# Game Boy MBC3 Multicart

This is a slightly updated design of my original flashable MBC3-based multicart for the Game Boy. You can make a 2-in-1 or 4-in-1 cartridge, that changes games based on a button press or power cycling the Game Boy. With this board you can also make a single game, but with the addition of a pressable reset button on the cartridge.

**This MBC3 cartridge uses new old stock 29F033 EEPROM chips and battery-backed SRAM.**

The features are as follows:

- Able to make a cartridge with either 2x 2 MB games or 4x 1 MB games
- Adds a pressable button to the cartridge (no shell cutting required)
  - The button can be configured to cycle games on the cart, reset the console, or both
- Configurable to have separate save data for each game, or to share the same save data across multiple games
- Fully compatible with the <a href="https://www.gbxcart.com/">GBxCart RW</a> so you can transfer games and save files to and from the board

Some examples of fun cartridges you can make with this board are:
- A single Pokemon game that has a reset button
- Both Pokemon Gold and Silver with separate saves
- Both Pokemon Gold and Silver with *the same* save (save files are compatible between versions!)
- Both Pokemon Gold and Silver with *the same* save that can switch between versions *during gameplay without resetting* (hotswap!)
- A single copy of Mary-Kate and Ashley - Pocket Planner with two separate save files



All gerbers and source files can be found in this repo, as this project is fully open source.

## Tutorial Video

Here's a video companion to this repository, but you will still need to read the repo to complete the build.

Multicart Video Tutorial (http://www.youtube.com/watch?v=DJ7rJUZhDuM "Game Boy Multicart Tutorial (Pokemon Gold and Silver)")

## Important Things Before You Start

1) To use this board, you need to have an original Game Boy game that uses an MBC3 mapper chip. <a href="https://catskull.net/gb-rom-database/">You can find a list of games and their mappers here</a>. Use the search function. Please note the RAM is in bytes, not bits. Since SRAM in this repo is defined in bits, you need to convert by multiplying the number of bytes by 8.
2) You will need to remove the MBC3 from your donor cartridge for use on this board. This will require a hot air rework station or a hot plate. There's a list below of other parts you can re-use from the donor cartridge.
3) When soldering parts on, it's a good idea to put kapton tape or otherwise cover the bottom cartridge edge. You do not want to get solder on the cartridge contacts.
4) I am not responsible for any damage you do to your self or your property. Attempt this project at your own risk.
5) I do not guarantee design compatibility. You may encounter issues with certain games. There is also a chance I have made an error in the design or the BOM - if this is the case, I will do everything I can to address the problem as quickly as possible.
6) If you are using this board to make games other than for personal use, you must have permission from the originator to use and distribute any ROM images or other related material. You are responsible for making sure you adhere to any license requirements.

DO NOT use my circuit boards for profiting from stolen work - this especially includes homebrew content, ROM hacks, and using fan-made labels without permission from the originator. **Support original creators!**

## Board Characteristics and Order Information

The zipped folder contains all the gerber files for this board. The following options **must** be chosen when ordering boards for yourself.

- Thickness: 0.8mm
- Surface Finish: ENIG
- Gold Fingers: Yes, 30° chamfer

You can use the zipped folder at any board fabricator you like. You may also buy the board from PCBWay using this link (disclosure: I receive 10% of the sale value to go twoards future PCB orders of my own):

<a href="https://www.pcbway.com/project/shareproject/Game_Boy_MBC3_Multicart_Updated_929c9a0f.html">PCB from PCBWay</a>

<a href="https://oshpark.com/shared_projects/x4BEUpR4">The board is also listed on OSH Park as well.</a> **Be sure to get them in 0.8mm thickness if you order from here.**

### Purchase from My Website

You can purchase this circuit board at my website, [https://mousebitelabs.store](https://mousebitelabs.store). Click the following image to be directed to the specific item listing:

<a href="https://mousebitelabs.store/products/game-boy-mbc3-multicart-circuit-board">PCB from MouseBiteLabs</a>

### Purchase from Etsy

I also offer the board on Etsy, if you would rather purchase through there - click the banner to be redirected.

<a href="https://mousebitelabs.etsy.com/listing/4363363543">PCB from Etsy</a> 

## Required Equipment

The EEPROM on the board needs to be programmed somehow. There are a few options for doing this:

1) <a href="https://www.gbxcart.com/">**GBxCart**</a>. This is a perfect option if you want an easy way to make Game Boy cartridges without a lot of extra effort. This is a standalone flasher that plugs into your computer via USB. The cartridge circuit board is fully compatible with it, and it makes reflashing games extremely easy using <a href="https://github.com/lesserkuma/FlashGBX">lesserkuma's FlashGBX software</a>.
2) At the lowest level, you can buy an EEPROM programmer with a TSOP chip programming adapter. The downside to this method is that you have to desolder the chip every time you want to program it. The <a href="https://flashcatusb.com/">FlashcatUSB</a> is one popular option in retro spaces, but I use the <a href="https://xgecu.myshopify.com/products/xgecu-new-t48-tl866-3gprogrammer-v12-01-support-28000-ics-for-spi-nor-nand-flash-emmc-bga153-162-169-100-221-tsop-sop-plcc">T48 programmer</a> with the <a href="https://xgecu.myshopify.com/products/100-original-xgecu-adp_f48_ex-1-tsop48-special-adapter-for-nor-flash-only-use-on-t48-tl866-3g-programmer">TSOP48 adapter</a>.

You may also be able to use the <a href="https://github.com/sanni/cartreader">**OSCR**</a> by sanni, but in order to do that you will need to prepare a single ROM file with both games and program it to the first game slot. Or, you will need to add a programming routine into the Arduino code to write a file without erasing the chip first. Consider yourself on your own for this until an addition to the OSCR repository is made to address this.

### How to Program the Cartridges

When using the GBxCart to program multiple games to the cartridge, it's recommended to turn SW2A and SW2B (detailed below) to the OFF position. To change ROM/RAM banks to program, simply press the SW1 tactile button between programming steps. Using FlashGBX's "Refresh" button should show that the game information on the left of the screen changes after pressing the button.

If you're programming the flash chip separate from the board, you'll need to concatenate all the ROM files together into one large 4 MB file to program the chip with.

<a href="https://github.com/MouseBiteLabs/Game-Boy-Cartridges/wiki">Also, you can check out the wiki for more information.</a>

## Battery Safety

When assembling a board, I recommend populating all the parts *except* the battery, and getting it to run initially without it. This is to make it easier to fix any solder connections that might need fixing, without having to worry about getting the battery hot. And if you need to rework anything near the battery after you've put it on the board, be safe and remove it before putting a hot soldering iron next to it.

And this should go without saying, but if you're assembling these boards with a hot plate or hot air, *do not* solder the battery on this way. You should use an iron, and keep heat off of the battery as much as possible. 

(Also check polarity!)

## Board Configurations

There's a lot to cover here. There are four separate switches to configure, and two different sizes of SRAM to pick from. You also can add a real-time clock to the cartridge for games that needed it.

*Note that you can simply solder bridges from the middle pads of the switches to the left or right to the "ON" or "OFF" positions, instead of installing an actual switch.*

### Real-Time Clock (RTC)

If your game uses an RTC, populate C2, R2, X1, and Z1 as indicated in the BOM.

If your game does *not* use the RTC function, you can omit these parts, but you also need to bridge the pads of Z1 with solder.



### SRAM Size Selection

There are two sizes of SRAM you can use, and the type you use will dictate how your save data is stored on the cartridge and if it's shared between games or not.

- If you use a 1 Mbit SRAM (like the AS6C1008), then each game you put on the cartridge will have its own separate save files. If you program multiple copies of the same game, then you can effectively have multiple save files on the same cart. Easy example is Pokemon games - they only let you have one save file, but if you put Pokemon Red on the multicart four times, then that gives you four separate save files!
- If you use a 256 Kbit SRAM (like the AS6C62256) then all the games you put on the cartridge will *share* the same RAM space.  This feature is probably only useful for Pokemon games. As an example: this means that if you made a cart that has Pokemon Red and Blue on it, you would play both versions with the same save data, as save data between the two games are compatible with each other.

### Game Cycling Mode Switch (SW2)

SW2, split into two separate switches SW2A (bottom half) and SW2B (top half), controls how you change games/save data on the cartridge. The following table describes the different settings:

| Mode | SW2A (Bottom) | SW2B (Top) | Game change with reset? | Game change with button press? | Does the button reset? |
| ---- | --- | --- | --- | --- | --- |
| 1 | OFF | OFF | No | Yes | Yes |
| 2 | OFF | ON | No | Yes | No |
| 3 | ON | OFF | Yes | Yes | Yes |
| 4 | ON | ON | Yes | No | No |

*Note: Mode 4 does not give function to the push button at all.*

The "game change" method in this table describes how you advance down the "game" columns described in the table for SW3.

### Game and Save Data Configuration Switch (SW3)

SW3, split into two separate switches SW3A (bottom half) and SW3B (top half), controls the order in which the ROM banks (the games) and the RAM banks (the save data) cycle. This table assumes you are using a 1 Mbit SRAM chip. If you are using a 256 Kbit SRAM, then every entry in the "RAM Banks" column can be described as "1x 256 Kbit", and all the "Game" columns will share that single RAM bank.

Please note that SW3A and SW3B are *different* than the SW3A and SW3B on the MBC5 Multicart PCB.

| Mode | SW3A (Top) | SW3B (Bottom) | ROM Banks  | RAM Banks | Game 1 | Game 2 | Game 3 | Game 4 |
| ---- | ---- | ---- | --- | --- | --- | --- | --- | --- |
| A | OFF  | ON | 2x 2 MB | 4x 256 Kbit | ROM1, RAM1 | ROM1, RAM2 | ROM2, RAM3 | ROM2, RAM4 |
| B | OFF  | OFF  | 4x 1 MB | 4x 256 Kbit | ROM1, RAM1 | ROM2, RAM2 | ROM3, RAM3 | ROM4, RAM4 |
| C | ON | ON | 2x 2 MB | 2x 256 Kbit | ROM1, RAM1 | ROM2, RAM2 | | |
| D | ON | OFF  | 2x 1 MB | 2x 256 Kbit | ROM1, RAM1 | ROM2, RAM2 | | |

*Note: Mode D is the same as Mode C, but with restricted space for the ROM, so there's no practical use for Mode D.*

### Game Mode Examples

Here's a list of example cartridges you can make with these settings:
1) Pokemon Red, Blue, Yellow, and Green on one cartridge with separate save files that changes only via pressing the button, which also resets the game: **Mode 1B** with 1 Mbit SRAM
2) Pokemon Gold and Silver with separate save files that changes by pressing the button *or* cycling power on the Game Boy: **Mode 3C** with 1 Mbit SRAM
3) Pokemon Gold and Silver with the same save file that hotswaps when you press the button on the cartridge (changing games during gameplay): **Mode 2C** with 256 Kbit SRAM

## Test Points and Final Checkout

On the back of the board are five test points. Here's where they are connected:

- TP1: SRAM supply voltage
- TP2: Battery voltage (after R1)
- TP3: Battery voltage (positive terminal of battery)
- TP4: Ground
- TP5: VCC input voltage

After you assemble your game, you should measure the current out of the battery. But first, you should program it with the GBxCart, or if you programmed the EEPROM separately, put it into a Game Boy and cycle power once. Then, flip the PCB upside down on a non-conductive surface (not your leg), and set your multimeter in DC millivolts (or volts). Put the positive probe on TP3 and the negative probe on TP2. If you used a 10kΩ for R1, as indicated in the BOM, you should read a voltage in the single or tens of millivolts for non-RTC games, or up to 60 mV for games using a real-time clock. If you have something much higher, especially voltages above 100mV, then you likely have an issue or short circuit on the board somewhere.

**Note: You need to power up the game at least once before battery currents will make sense - the battery management ICs can start up in an unknown state before applying main power to the board.**

To estimate battery life, see <a href="https://github.com/MouseBiteLabs/Game-Boy-MBC3-Cartridge/tree/main/Technical#estimating-battery-life">this section in the Technical Design Document of my first MBC3 design</a>, or for more in-depth analysis, <a href="https://hackaday.io/project/11864-tritiled/log/72554-determining-maximum-runtime-176-to-202-years-cr2032">this Hackaday post</a>.

### Current Draw Measurements and Battery Selection

The revision of MBC3 chip you are using will influence how much current draw you get, and thus how long your battery life will last. For the test set up, I am replacing the battery with a regulated DC power supply set for 3 VDC for consistency, on my regular MBC3 cart board with an MM1134 chip for U4, and brand new AS6C62256 SRAM.

These numbers are for reference only - to help you decide which MBC3 revision to use for your game, if you have a choice. These numbers are similar to a regular MBC3 cartridge, but the current required for retaining save data on the multicart will be slightly higher (about 0.2 uA) due to the extra components.

| Rev | P/N | Current draw (without RTC) | Battery Life Estimate (no RTC, CR2025) | Current draw (with RTC) | Battery Life Estimate (RTC, CR2025)  |
| ----- | --- | --- | --- | --- | --- |
| MBC3A | LR38536B | 0.4 uA | 47 years | 1.7 uA | 11 years |
| MBC3A | BU3632K  | 0.7 uA | 27 years | 1.7 uA | 11 years |
| MBC3A | P-2 | 0.7 uA | 27 years | 4.1 uA | 5 years |
| MBC3B | BU3634K  | 0.8 uA | 24 years | 1.7 uA | 11 years |
| MBC3B | P-2 | 0.6 uA | 31 years | 3.9 uA | 5 years |

Here is the same table, but with AS6C1008 SRAM instead of AS6C62256. It draws approximately 1 uA more than the AS6C62256.

| Rev | P/N | Current draw (without RTC) | Battery Life Estimate (no RTC, CR2025) | Current draw (with RTC) | Battery Life Estimate (RTC, CR2025)  |
| ----- | --- | --- | --- | --- | --- |
| MBC3A | LR38536B | 1.4 uA | 13 years | 2.7 uA | 7 years |
| MBC3A | BU3632K  | 1.7 uA | 11 years | 2.7 uA | 7 years |
| MBC3A | P-2 | 1.7 uA | 11 years | 5.1 uA | 4 years |
| MBC3B | BU3634K  | 1.8 uA | 10 years | 2.7 uA | 7 years |
| MBC3B | P-2 | 1.6 uA | 12 years | 4.9 uA | 4 years |

*If you have one of the revisions of MBC3 chips is missing from the table, please contact me!*

### Battery Size Considerations

The coin cells commonly used on Game Boy carts in order of increasing size are CR2016, CR2025, and CR2032. The CR2032 is the thickest, but yields the longest battery life.

Batteries that are as large as CR2032 will fit inside the shell, *however*, due to the thickness of the CR2032, using one makes it so the shell cannot be pressed down very easily. This makes the button inside the shell difficult to press reliably. For this reason, I recommend using the CR2025. If you want to use a CR2032 for a bit longer battery life, you should only expect to make a cart that changes games via power cycling only (Modes 3 or 4).

I haven't tested it, but I believe using battery holders instead of pre-tabbed batteries will similarly cause issues with trying to press the button in the middle of the cartridge.

## Board Fitment

The shape of this board was originally meant to mimic original Game Boy circuit boards as closely as possible. Unfortunately, when placed in some aftermarket Game Boy cartridge shells (like those from Cloud Game Store), the circuit board has a lot of freedom to rotate around the main screw hole in the bottom-middle of the cartridge. This can cause misalignment when you put it in a Game Boy, which can cause a game to either not load properly (garbled Game Boy logo) or shut off the Game Boy because of a short circuit. This isn't *dangerous* or anything, just annoying.

In order to make the boards fit nicer in any kind of shell, I added extended tabs of circuit board material to the edges of the cartridges to keep it from rotating too much in shells, which was suggested to me by <a href="https://github.com/orangeglo">orangeglo</a>! (Thanks!)

If you're having trouble fitting the circuit board into a shell, because the tabs interfere with the cart edges, you can safely sand or trim them down as there is no copper within the tabs themselves. The only shell that appears to require any kind of trimming are Kitsch-Bent shells.

## Bill of Materials (BOM)

| Reference Designators | Value/Part Number | Package | Description | Source |
| --- | --- | --- | --- | --- |
| B1 | CR2025, CR2016, CR2032*| See note above | Backup Battery | [https://mou.sr/3PLccol](https://mou.sr/3PLccol) |
| C1 | 0.1uF | 0603 | Capacitor (MLCC) | [https://mou.sr/3ENc15O](https://mou.sr/3ENc15O) |
| C2 | 15 pF | 0603 | Capacitor (MLCC) | [https://mou.sr/3PPorjO](https://mou.sr/3PPorjO) |
| Z1 | 15 pF | 0603 | Capacitor (MLCC) | [https://mou.sr/3PPorjO](https://mou.sr/3PPorjO) |
| C4 | 0.1uF | 0603 | Capacitor (MLCC) | [https://mou.sr/3ENc15O](https://mou.sr/3ENc15O) |
| C5 | 0.1uF | 0603 | Capacitor (MLCC) | [https://mou.sr/3ENc15O](https://mou.sr/3ENc15O) |
| C6 | 10uF | 0603 | Capacitor (MLCC) | [https://mou.sr/3mZtSkF](https://mou.sr/3mZtSkF) |
| C7 | 0.1uF | 0603 | Capacitor (MLCC) | [https://mou.sr/3ENc15O](https://mou.sr/3ENc15O) |
| C8 | 0.01uF | 0603 | Capacitor (MLCC) | [https://mou.sr/3AsRwK1](https://mou.sr/3AsRwK1) |
| Q1 | 2N7002 | SOT-23 | N-Channel FET | [https://mou.sr/3rgfh6J](https://mou.sr/3rgfh6J) |
| R1 | 10k | 0603 | Resistor | [https://mou.sr/3riR7IH](https://mou.sr/3riR7IH) |
| R2 | 330k | 0603 | Resistor | [https://mou.sr/3PZ2pvj](https://mou.sr/3PZ2pvj) |
| R5 | 130k | 0603 | Resistor | [https://mou.sr/3MjXliy](https://mou.sr/3MjXliy) |
| R6 | 130k | 0603 | Resistor | [https://mou.sr/3MjXliy](https://mou.sr/3MjXliy) |
| R9 | 130k | 0603 | Resistor | [https://mou.sr/3MjXliy](https://mou.sr/3MjXliy) |
| R10 | 49.9k | 0603 | Resistor | [https://mou.sr/3Q3NRZO](https://mou.sr/3Q3NRZO) |
| SW1 | See note | 5.2 x 5.2mm | Tactile Switch | See Note |
| SW2 | CAS-D20TA | J Form Lead | Dual SPDT | [https://mou.sr/44YZNT5](https://mou.sr/44YZNT5) |
| SW3 | CAS-D20TA | J Form Lead | Dual SPDT | [https://mou.sr/44YZNT5](https://mou.sr/44YZNT5) |
| U1 | 29F032, 29F033 | TSOP-40 | Flash EEPROM | AliExpress or eBay |
| U2 | MBC3A or MBC3B | QFP-32 | MBC3 Mapper | Donor MBC3 Game Boy cartridge |
| U3 | AS6C62256, AS6C1008 | SOP-28, SOP-32 | SRAM | [https://mou.sr/3sFegFF](https://mou.sr/3sFegFF) |
| U4 | TPS3613 | MSOP-10 | Battery Management | [https://mou.sr/45Ir2kh](https://mou.sr/45Ir2kh) |
| U5 | SN74HCS74 | TSSOP-14 | Dual Flip Flop | [https://mou.sr/3QYGEuT](https://mou.sr/3QYGEuT) |
| U6 | SN74AHC1G126 | SC70 | Tri-State Buffer | [https://mou.sr/3T9Zdim](https://mou.sr/3T9Zdim) |
| U7 | SN74AHC1G126 | SC70 | Tri-State Buffer | [https://mou.sr/3T9Zdim](https://mou.sr/3T9Zdim) |
| U8 | SN74AHC1G126 | SC70 | Tri-State Buffer | [https://mou.sr/3T9Zdim](https://mou.sr/3T9Zdim) |
| X1 | 32.768 kHz | Radial | Crystal Oscillator | [https://mou.sr/3ZteKuy](https://mou.sr/3ZteKuy) |

### Note about SW1

If SW1 is long enough, it will sit inside the shell in a way that lets you press it by lightly pressing on the cartridge shell. This way, you can activate it without removing it from the console. You need to find a switch that has an extended stem on AliExpress, eBay, or Amazon (**if you find a compatible switch on Mouser or Digikey, please let me know**). The measurements will be 5.2 mm x 5.2 mm, with a height of 3.5 mm. Sometimes these parts are listed as "4 mm x 4 mm" or "5 mm x 5 mm" instead. Check the datasheet, if available, to see if it'll fit the footprint. They should have listing pictures similar to the ones seen here:



### Note about SW2, SW3

Instead of using the somewhat pricey switch designated for SW2 and SW3, you can instead just bridge the pads with solder from the middle pad to the pad in the direction you want to set the switch to. For example - in the below picture, SW3A and SW3B are both in the "ON" position in both cases. (Note that the white switches on the right image are switched to the right.)



### Note about MBC3 Revisions

If you have a choice, I recommend against using the original revision-less MBC3 mapper for this specific circuit board. You should use an MBC3A or MBC3B if possible. Save the revision-less MBC3 chips for regular MBC3 cartridges!



*[Images of MBC3 chips from <a href="https://gbhwdb.gekkio.fi/cartridges/mbc3.html">Game Boy Hardware Database</a>.]*

### Usable Donor Cartridge Parts

You can use a few parts from the donor cart on the new board to save some money. Note that you will generally get better reliability with new parts as opposed to old ones. For example: I have seen failed RAM chips from donors in the past.

1) **C2, R2, X1, Z1: RTC Components** - You can move over these parts if you're using the real-time clock function. Note that Z1 and C2 are designated as C2 and C3 on my board. They're the same value, so they're interchangeable.
2) **U2: MBC3A or MBC3B** - This one is required
3) **U3: SRAM** - You can use this part *only if* the sum of the RAM space for the games you're using is the same or less amount of RAM that the donor cartridge has. If you plan to have separate save data for every game, you'll probably need to buy an AS6C1008.

You could probably transfer over most of the 0.1uF capacitors but they're pretty cheap anyway, so I generally just recommend buying new resistors and capacitors.

## Things to Remember

- The 29F032 and 29F033 have been known to occasionally be defective upon arrival. They're either used, or new old stock, and usually only available from AliExpress.
- The footprint for the battery can fit a CR2032, CR2025, or CR2016 with solder tabs. The only difference is the mAh capacity (larger number = longer life). If you get Panasonic tabbed batteries, you may have to trim the battery tabs to make them fit on the footprint.
- Generally, ROM sizes are conveyed in terms of kilobytes and megabytes (KB, MB). RAM size is usually conveyed in terms of kilobits or megabits (Kbit, Mbit). You can convert Kbit and Mbit to KB and MB by dividing Kbit or Mbit by 8. For example, 256 Kbit = 32 KB.

## Labels

If you want a Bucket Mouse branded label for your cartridge, look no further than <a href="https://krizdingus.com/mousebitelabs/">krizdingus's designs</a>. Special thanks to Kris for designing these, they look awesome! (If you are going to order/print these, use the high-res images hosted on his website, and *keep the labels for personal or non-commercial use only.*)



## Why not FRAM?

This particular board is designed for using low retention power SRAM, or Static RAM. One downside to SRAM is that you need a battery to keep the SRAM powered on even when the game is turned off if you want to retain the data on the chip. So eventually the battery will die, and your save data will be lost.

The other popular option for holding save data is using FRAM, or Ferroelectric RAM, to keep save data around even after the battery dies (specifically, the popular part that's used for Game Boy FRAM carts is the FM18W08).

So, why would anyone ever use SRAM over FRAM if FRAM doesn't need a battery? Well, they do come with a number of downsides:

1) Quality, new stock, 5V tolerant FRAM is expensive ($12+ per part).
2) Cheaper FRAM chips from eBay or Aliexpress are notoriously flaky (anecdotally, ~50% success rate).
3) **FM18W08 maxes out at 256K (which is restrictive for multicarts).**
4) FRAM memory access requires different chip select timing than SRAM, and the Game Boy expects SRAM, so it is not natively compatible with FRAM carts. The Gameboy Color specifically cannot (easily) be made to properly access FM18W08 chip. You *can* use an OR gate and add the CLK on the cart edge to try to achieve the necessary timing, but it only works (properly) for DMG/MGB/SGB, not the GBC. It usually *works* in practice for GBC, but it's technically a datasheet violation and can potentially cause issues in edge cases. <a href="https://github.com/Gekkio">(Thanks to gekkio for pointing this out!)</a>

In contrast, *brand new* quality SRAM chips are ~$3, and you can even save that by using the original SRAM from a donor cartridge if you want to. You will easily get more than a decade of life running on a battery. You're already assembling this cartridge; you can dump the save and replace the battery before then.

## Revision History

### v2.1
- Fixed missing trace on D6 line
- Added triangles to U4 and U5 silkscreen

### v2.0
- Fixed issue with previous design where SW2A being in the ON position caused excess save battery drain
- Added board number to the top of the board
- Updated silkscreen and cartridge style to match my other Game Boy cartridges
- Removed R8, made EEPROM writable via the /WR pin on the cart edge

### v1.3
- Fixed debounce circuit for push button
- Adjusted board edge tabs to better fit in shells

### v1.2
- Changed C3 to Z1
- Added nubs on the board edge to prevent the circuit board from rattling around in aftermarket cartridges

### v1.1
- Fix schematic errors
- Extended cart edge down by 0.25 mm for better fitment
- Added OSHW logo and "SUPPORT ORIGINAL CREATORS!"

### v1.0
- Prototype revision

## Resources and Acknowledgements

- <a href="http://www.devrs.com/gb/files/hardware.html">Jeff Frohwein's GameBoy Tech Page</a>
- <a href="https://gbhwdb.gekkio.fi/">Game Boy Hardware Database</a>
- <a href="https://catskull.net/gb-rom-database/">Nintendo Gameboy Game List</a>
- <a href="https://www.gbxcart.com/">insideGadgets discord server for GBxCart RW compatibility requirements</a>
- <a href="https://github.com/lesserkuma/FlashGBX">Lesserkuma's FlashGBX software</a>
- <a href="https://www.ti.com/lit/ds/symlink/tps3613-01.pdf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">TPS3613 Datasheet</a>
- Board outline modified from <a href="https://tinkerer.us/projects/homebrew-gameboy-cartridge.html">Dillon Nichols's Homebrew Gameboy Cartridge project</a>
- Thanks to <a href="https://github.com/orangeglo">orangeglo</a> for his suggestion of adding spacers around the board edge for better fitment in aftermarket cartridges
- Some components from <a href="https://github.com/adafruit/Adafruit-Eagle-Library">Adafruit's Eagle parts library</a>
- Some components from <a href="https://www.snapeda.com/">SnapMagic</a>
- Thank you to <a href="https://github.com/Gekkio">gekkio</a> for their deep Game Boy knowledge resources, and for collaboration in demystifying some of the design choices on Game Boy cartridges

## License

<br />This work is licensed under a <a rel="license" href="http://creativecommons.org/licenses/by-sa/4.0/">Creative Commons Attribution-ShareAlike 4.0 International License</a>. You are able to copy and redistribute the material in any medium or format, as well as remix, transform, or build upon the material for any purpose (even commercial) - but you **must** give appropriate credit, provide a link to the license, and indicate if any changes were made.

©MouseBiteLabs 2025

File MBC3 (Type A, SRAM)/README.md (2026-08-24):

# Game Boy MBC3 Cartridge - Type A, SRAM

This is an updated design of my flashable MBC3-based cartridge for the Game Boy. The MBC3 mapper improves a lot over the MBC1, and includes a real-time clock for everyone's favorite battery-sucking game.... Mary Kate and Ashley Pocket Planner! Oh, and Pokemon.

**This MBC3 cartridge uses brand new M29F160 EEPROM chips and battery-backed SRAM.**

This circuit board should cover most, if not all, MBC3 games. The features are as follows:

- Able to make games up to 2 MB in size, that use up to 256 Kbit of RAM
- Compatibility with all four of the popular Game Boy battery management ICs - MM1026, MM1134, BA6129, and BA6735
- The option to add battery backup to the cartridge *without* the need of the original battery management ICs
- Fully compatible with both the <a href="https://www.gbxcart.com/">GBxCart RW</a> and sanni's <a href="https://github.com/sanni/cartreader">Open Source Cart Reader (OSCR)</a> so you can transfer games and save files to and from the board



All gerbers and source files can be found in this repo, as this project is fully open source.

## Important Things Before You Start

1) To use this board, you need to have an original Game Boy game that uses an MBC3 mapper chip. <a href="https://catskull.net/gb-rom-database/">You can find a list of games and their mappers here</a>. Use the search function. Please note the RAM is in bytes, not bits. Since SRAM in this repo is defined in bits, you need to convert by multiplying the number of bytes by 8.
2) You will need to remove the MBC3 from your donor cartridge for use on this board. This will require a hot air rework station or a hot plate. There's a list below of other parts you can re-use from the donor cartridge.
3) When soldering parts on, it's a good idea to put kapton tape or otherwise cover the bottom cartridge edge. You do not want to get solder on the cartridge contacts.
4) I am not responsible for any damage you do to your self or your property. Attempt this project at your own risk.
5) I do not guarantee design compatibility. You may encounter issues with certain games. There is also a chance I have made an error in the design or the BOM - if this is the case, I will do everything I can to address the problem as quickly as possible.
6) If you are using this board to make games other than for personal use, you must have permission from the originator to use and distribute any ROM images or other related material. You are responsible for making sure you adhere to any license requirements.

DO NOT use my circuit boards for profiting from stolen work - this especially includes homebrew content, ROM hacks, and using fan-made labels without permission from the originator. **Support original creators!**

## Board Characteristics and Order Information

The zipped folder contains all the gerber files for this board. The following options **must** be chosen when ordering boards for yourself.

- Thickness: 0.8mm
- Surface Finish: ENIG
- Gold Fingers: Yes, 30° chamfer

You can use the zipped folder at any board fabricator you like. You may also buy the board from PCBWay using this link (disclosure: I receive 10% of the sale value to go twoards future PCB orders of my own):

<a href="https://www.pcbway.com/project/shareproject/Game_Boy_MBC3_Cartridge_M29F160_SRAM_6fc0c16b.html">PCB from PCBWay</a>

<a href="https://oshpark.com/shared_projects/ahA0HcIn">The board is also listed on OSH Park as well.</a> **Be sure to get them in 0.8mm thickness if you order from here.**

### Purchase from My Website

You can purchase this circuit board at my website, [https://mousebitelabs.store](https://mousebitelabs.store). Click the following image to be directed to the specific item listing:

<a href="https://mousebitelabs.store/products/game-boy-mbc3-flash-cartridge-circuit-board">PCB from MouseBiteLabs</a>

### Purchase from Etsy

I also offer the board on Etsy, if you would rather purchase through there - click the banner to be redirected.

<a href="https://mousebitelabs.etsy.com/listing/1880157700/game-boy-cartridge-pcb-mbc3-type-a">PCB from Etsy</a> 

## Required Equipment

The EEPROM on the board needs to be programmed somehow. There are a few options for doing this:

1) <a href="https://www.gbxcart.com/">**GBxCart**</a>. This is a perfect option if you want an easy way to make Game Boy cartridges without a lot of extra effort. This is a standalone flasher that plugs into your computer via USB. The cartridge circuit board is fully compatible with it, and it makes reflashing games extremely easy using <a href="https://github.com/lesserkuma/FlashGBX">lesserkuma's FlashGBX software</a>.
2) <a href="https://github.com/sanni/cartreader">**OSCR**</a> by sanni. This is the Open Source Cart Reader, capable of making backups of both the ROM and RAM contents of cartridges across many different systems - like the NES, SNES, Genesis, and of course Game Boy and Game Boy Advance. And you can also use it to flash these Game Boy cartridges. The OSCR however requires assembly (or someone to assemble it for you) and is a bit more cumbersome to interface with on a PC, but it's an extremely powerful tool that I can't recommend enough if you want to expand past Game Boys.
3) At the lowest level, you can buy an EEPROM programmer with a TSOP chip programming adapter. The downside to this method is that you have to desolder the chip every time you want to program it. The <a href="https://flashcatusb.com/">FlashcatUSB</a> is one popular option in retro spaces, but I use the <a href="https://xgecu.myshopify.com/products/xgecu-new-t48-tl866-3gprogrammer-v12-01-support-28000-ics-for-spi-nor-nand-flash-emmc-bga153-162-169-100-221-tsop-sop-plcc">T48 programmer</a> with the <a href="https://xgecu.myshopify.com/products/100-original-xgecu-adp_f48_ex-1-tsop48-special-adapter-for-nor-flash-only-use-on-t48-tl866-3g-programmer">TSOP48 adapter</a>.

## Battery Safety

When assembling a board, I recommend populating all the parts *except* the battery, and getting it to run initially without it. This is to make it easier to fix any solder connections that might need fixing, without having to worry about getting the battery hot. And if you need to rework anything near the battery after you've put it on the board, be safe and remove it before putting a hot soldering iron next to it.

If you're assembling these boards with a hot plate or hot air, *do not* solder the battery on this way. You should use an iron, and keep heat off of the battery as much as possible. 

(Also check polarity!)

## Board Configurations

The board comes with five sets of jumper pads for solder bridges. SJ3, SJ5, and SJ6 require you to solder bridge the middle pad either to the left or right pads. SJ1 and SJ4 are configured by either leaving them alone or bridging them with solder. Here are the situations where you need to add solder bridges.

**<a href="https://github.com/MouseBiteLabs/Game-Boy-Cartridges/wiki/MBC3">You can check out the wiki for some pictures of boards in various configurations to follow along with.</a>**

### Making Games Without SRAM or Battery (SJ1 and SJ4)

Solder bridge SJ1 and SJ4 if your game does not use any SRAM or battery. I don't believe there were ever any MBC3 games made *without* SRAM, but if you wanted to... remove it for some reason, you can.

### MBC3 Type Select (SJ3)

The MBC3 chip you use from the donor cartridge can be one of a few different types:

- If your MBC3 doesn't have a revision letter on it (it just says "MBC3" on it) then bridge the middle pad of SJ3 to the left. (You will also need to populate Q1!)
- If your MBC3 *does* have a revision letter, such as MBC3A or MBC3B, then bridge the middle pad of SJ3 to the right.



*[Images of MBC3 chips from <a href="https://gbhwdb.gekkio.fi/cartridges/mbc3.html">Game Boy Hardware Database</a>.]*

### RAM Size Selection (SJ5 and SJ6, or SW1)

These jumpers are located underneath the MBC3 chip, and labeled "64K" and "256K". Solder them to configure the amount of RAM your cart uses. You must configure these pads for every game you make, unless you do not need RAM. <a href="https://catskull.net/gb-rom-database/">You can find a list of games here with their respective RAM sizes.</a>

- If the game you're making uses 256 Kbit of RAM, then solder the middle pads of the two jumper sets to the right pads.
- If the game you're making uses 64 Kbit of RAM, then solder the middle pads of the two jumper sets to the left pads.
- SJ5 and SJ6 must be soldered in the same direction.
- The footprint of these selection pads should allow for a DPDT switch, part number CAS-220A1, to be placed on these pads instead of having to bridge the pads with solder.

Note that you can make games that only require 64 Kbit of RAM and still use a 256 Kbit SRAM chip. You still need to configure the jumpers to the 64 Kbit setting, though.



### Games Without a Real-Time Clock

If your game does *not* use the RTC function with the crystal X1, then you need to bridge the pads of Z1.



## Test Points and Final Checkout

On the back of the board are five test points. Here's where they are connected:

- TP1: SRAM supply voltage
- TP2: Battery voltage (after R1)
- TP3: Battery voltage (positive terminal of battery)
- TP4: Ground
- TP5: VCC input voltage

After you assemble your game, you should measure the current out of the battery. But first, you should program it with the GBxCart, or if you programmed the EEPROM separately, put it into a Game Boy and cycle power once. Then, flip the PCB upside down on a non-conductive surface (not your leg), and set your multimeter in DC millivolts (or volts). Put the positive probe on TP3 and the negative probe on TP2. If you used a 10kΩ for R1, as indicated in the BOM, you should read a voltage in the single or tens of millivolts for non-RTC games, or up to 40 mV for games using a real-time clock. If you have something much higher, especially voltages above 40mV, then you likely have an issue or short circuit on the board somewhere.

**Note: You need to power up the game at least once before battery currents will make sense - the battery management ICs can start up in an unknown state before applying main power to the board.**

To estimate battery life, see <a href="https://github.com/MouseBiteLabs/Game-Boy-MBC3-Cartridge/tree/main/Technical#estimating-battery-life">this section in the Technical Design Document of my first MBC3 board design</a>, or for more in-depth analysis, <a href="https://hackaday.io/project/11864-tritiled/log/72554-determining-maximum-runtime-176-to-202-years-cr2032">this Hackaday post</a>.

### Current Draw Measurements

The revision of MBC3 chip you are using will influence the current draw out of the battery when the game is off, and thus how long your battery life will last. Using the real-time clock function on the MBC3 will draw more current than if you do not.

For the test set up, I am replacing the battery with a regulated DC power supply set for 3 VDC for consistency, on a cart board with an MM1134 chip for U4, and brand new AS6C62256 SRAM. The "no RTC" measurements have Z1 (or C3) shorted, and the "with RTC" measurements have R2, C2, Z1, and X1 populated. I am using a Fluke 117 Multimeter in DC mV mode for measurements.

| Rev | P/N | Current draw (without RTC) | Battery Life Estimate (no RTC, CR2025) | Current draw (with RTC) | Battery Life Estimate (RTC, CR2025)  | Battery Life Estimate (RTC, CR2032) |
| ----- | --- | --- | --- | --- | --- | --- |
| MBC3  | LR385364 | 0.2 uA | >50 years | 1.8 uA | 10 years | 14 years |
| MBC3  | BU3631K  | 0.6 uA | 31 years | 1.6 uA | 12 years | 16 years |
| MBC3  | P-1 | 0.4 uA | 47 years | 3.8 uA | 5 years | 7 years |
| MBC3A | LR38536B | 0.2 uA | >50 years | 1.5 uA | 13 years | 18 years |
| MBC3A | BU3632K  | 0.5 uA | 37 years | 1.5 uA | 13 years | 18 years |
| MBC3A | P-2 | 0.5 uA | 37 years | 3.9 uA | 5 years | 7 years |
| MBC3B | BU3634K  | 0.6 uA | 31 years | 1.5 uA | 13 years | 18 years |
| MBC3B | P-2 | 0.4 uA | 47 years | 3.7 uA | 5 years | 7 years |

*Note: The SRAM I used, AS6C62256, drew 0.05 uA by itself for these tests. Your current draw may vary depending on the SRAM you are using.*

## Board Fitment

The shape of this board was originally meant to mimic original Game Boy circuit boards as closely as possible. Unfortunately, when placed in some aftermarket Game Boy cartridge shells (like those from Cloud Game Store), the circuit board has a lot of freedom to rotate around the main screw hole in the bottom-middle of the cartridge. This can cause misalignment when you put it in a Game Boy, which can cause a game to either not load properly (garbled Game Boy logo) or shut off the Game Boy because of a short circuit. This isn't *dangerous* or anything, just annoying.

In order to make the boards fit nicer in any kind of shell, I added extended tabs of circuit board material to the edges of the cartridges to keep it from rotating too much in shells, which was suggested to me by <a href="https://github.com/orangeglo">orangeglo</a>! (Thanks!)

If you're having trouble fitting the circuit board into a shell, because the tabs interfere with the cart edges, you can safely sand or trim them down as there is no copper within the tabs themselves. The only shell that appears to require any kind of trimming are Kitsch-Bent shells.
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

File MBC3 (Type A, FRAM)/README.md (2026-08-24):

# Game Boy MBC3 Cartridge - Type A, FRAM

# DESIGN IS UNVERIFIED (but probably ok)

This is an alternate design of my <a href="https://github.com/MouseBiteLabs/Game-Boy-Cartridges/tree/main/MBC3%20(Type%20A%2C%20SRAM)">flashable MBC3-based cartridge for the Game Boy</a>. This board uses non-volatile FRAM instead of SRAM to hold save data. I made this specifically for use with the <a href="https://github.com/MouseBiteLabs/Super-Game-Boy-Plus/tree/main">Super Game Boy Plus boards.</a> Even though the board uses FRAM for the save data, the real-time clock data is stored on the MBC3 chip itself, and therefore a battery is included to keep the MBC3 powered on while the Game Boy is off, to keep the time in memory. If the battery dies, your save data will still be available on the FRAM chip, meaning swapping a dead battery to restore clock function will not risk any save data.

**This MBC3 cartridge uses brand new M29F160 EEPROM chips and non-volatile FRAM.**

This circuit board should cover most MBC3 games, and is able to make games up to 2 MB in size, that use up to 256 Kbit of RAM. It is fully compatible with both the <a href="https://www.gbxcart.com/">GBxCart RW</a> and sanni's <a href="https://github.com/sanni/cartreader">Open Source Cart Reader (OSCR)</a> so you can transfer games and save files to and from the board. Because of the FRAM this board utilizes, <a href="https://github.com/MouseBiteLabs/Game-Boy-Cartridges/tree/main/MBC3%20(Type%20A%2C%20SRAM)#why-not-fram">it is technically only fully compatible with regular Game Boy games, and not Game Boy Color games,</a> though no issues have been reported in the past when using them with Game Boy Color games.



All gerbers and source files can be found in this repo, as this project is fully open source.

## Important Things Before You Start

1) To use this board, you need to have an original Game Boy game that uses an MBC3 mapper chip. <a href="https://catskull.net/gb-rom-database/">You can find a list of games and their mappers here</a>. Use the search function. Please note the RAM is in bytes, not bits. Since RAM in this repo is defined in bits, you need to convert by multiplying the number of bytes by 8.
2) You will need to remove the MBC3 from your donor cartridge for use on this board. This will require a hot air rework station or a hot plate. There's a list below of other parts you can re-use from the donor cartridge.
3) When soldering parts on, it's a good idea to put kapton tape or otherwise cover the bottom cartridge edge. You do not want to get solder on the cartridge contacts.
4) I am not responsible for any damage you do to your self or your property. Attempt this project at your own risk.
5) I do not guarantee design compatibility. You may encounter issues with certain games. There is also a chance I have made an error in the design or the BOM - if this is the case, I will do everything I can to address the problem as quickly as possible.
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

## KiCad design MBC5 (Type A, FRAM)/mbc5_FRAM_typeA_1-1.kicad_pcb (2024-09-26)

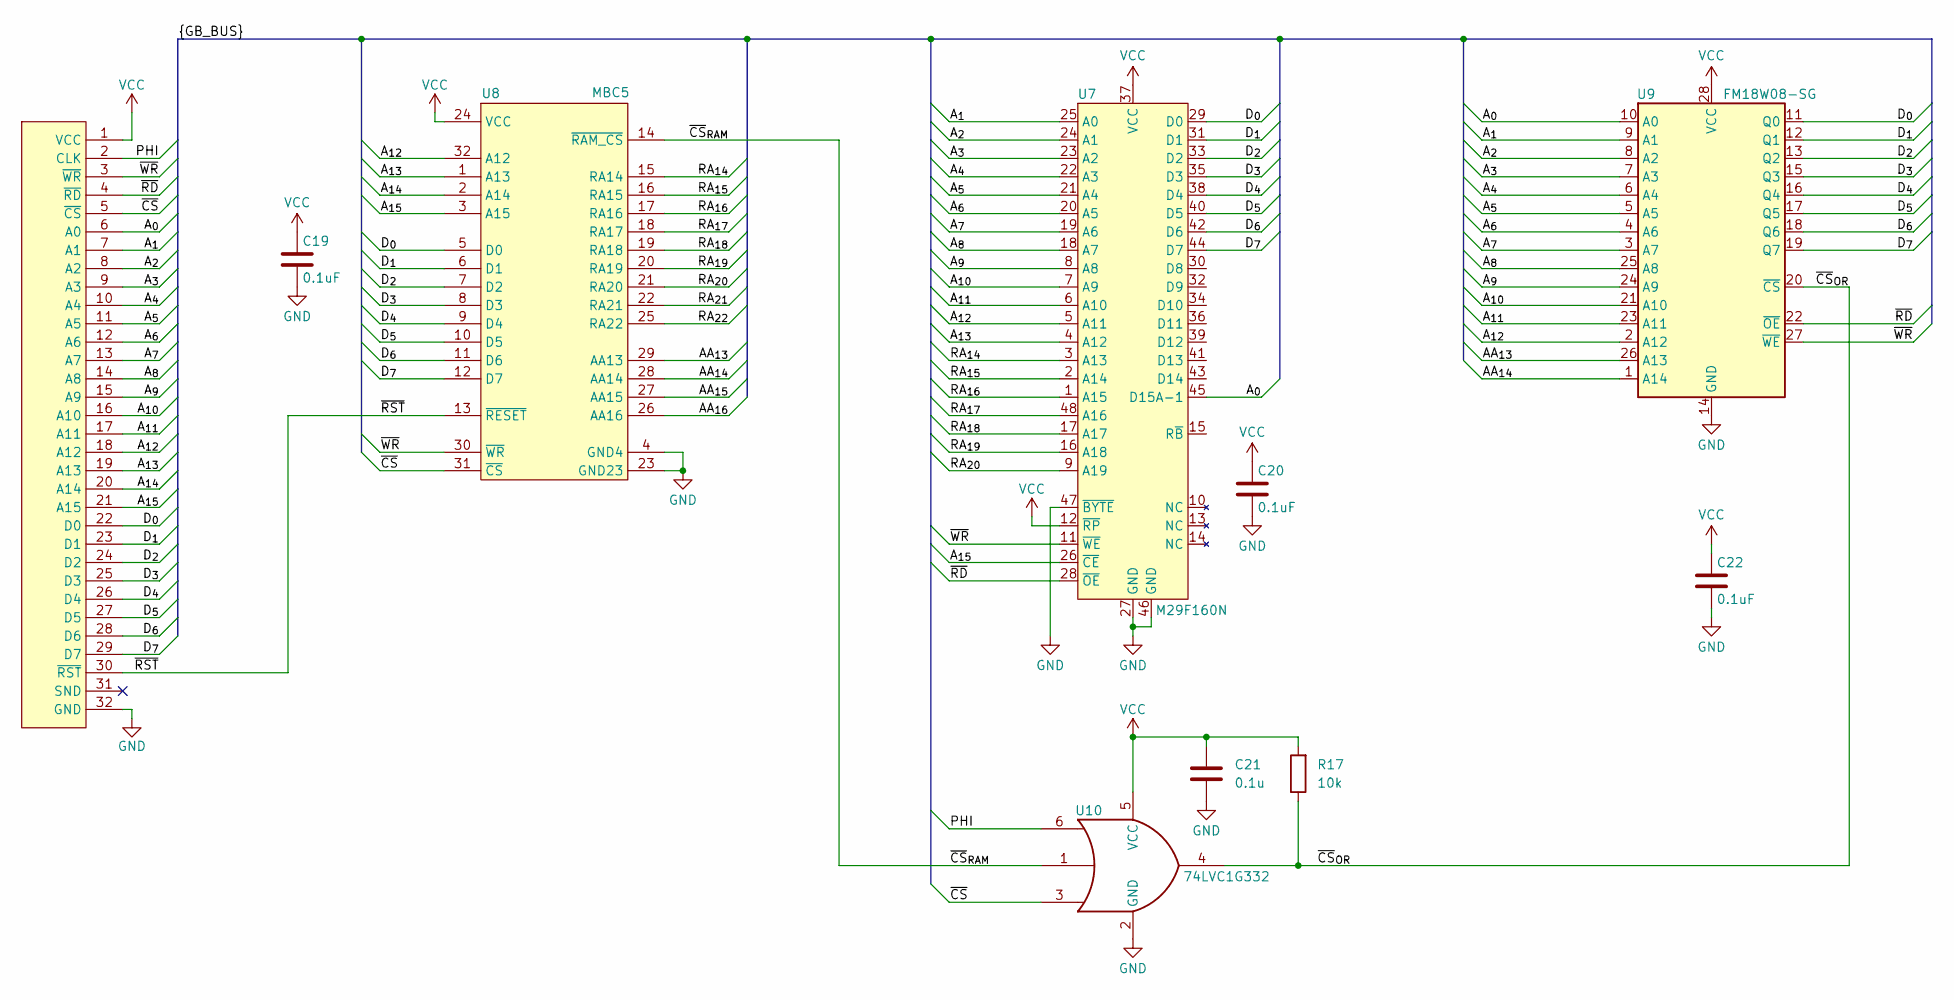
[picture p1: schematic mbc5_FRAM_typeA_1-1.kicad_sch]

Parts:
C19, C20, C22: 0.1uF; C_0603_1608Metric_Boxed
C21: 0.1u; C_0603_1608Metric_Boxed
P1: GBC_CARTTAB; GBC_CART_TABBED
R17: 10k; R_0603_1608Metric_Boxed
U7: M29F160N; TSOP-I-48_18.4x12mm_P0.5mm
U8: MBC5; QFP-32
U9: FM18W08-SG; SO28
U10: 74LVC1G332; SOT-363_SC-70-6

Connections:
/AA_{13}: U8.29 (AA13), U9.26 (A13)
/AA_{14}: U8.28 (AA14), U9.1 (A14)
/AA_{15}: U8.27 (AA15)
/AA_{16}: U8.26 (AA16)
/A_{0}: P1.6 (A0), U7.45 (D15A-1), U9.10 (A0)
/A_{1}: P1.7 (A1), U7.25 (A0), U9.9 (A1)
/A_{2}: P1.8 (A2), U7.24 (A1), U9.8 (A2)
/A_{3}: P1.9 (A3), U7.23 (A2), U9.7 (A3)
/A_{4}: P1.10 (A4), U7.22 (A3), U9.6 (A4)
/A_{5}: P1.11 (A5), U7.21 (A4), U9.5 (A5)
/A_{6}: P1.12 (A6), U7.20 (A5), U9.4 (A6)
/A_{7}: P1.13 (A7), U7.19 (A6), U9.3 (A7)
/A_{8}: P1.14 (A8), U7.18 (A7), U9.25 (A8)
/A_{9}: P1.15 (A9), U7.8 (A8), U9.24 (A9)
/A_{10}: P1.16 (A10), U7.7 (A9), U9.21 (A10)
/A_{11}: P1.17 (A11), U7.6 (A10), U9.23 (A11)
/A_{12}: P1.18 (A12), U7.5 (A11), U8.32 (A12), U9.2 (A12)
/A_{13}: P1.19 (A13), U7.4 (A12), U8.1 (A13)
/A_{14}: P1.20 (A14), U8.2 (A14)
/A_{15}: P1.21 (A15), U7.26 (~CE), U8.3 (A15)
/D_{0}: P1.22 (D0), U7.29 (D0), U8.5 (D0), U9.11 (Q0)
/D_{1}: P1.23 (D1), U7.31 (D1), U8.6 (D1), U9.12 (Q1)
/D_{2}: P1.24 (D2), U7.33 (D2), U8.7 (D2), U9.13 (Q2)
/D_{3}: P1.25 (D3), U7.35 (D3), U8.8 (D3), U9.15 (Q3)
/D_{4}: P1.26 (D4), U7.38 (D4), U8.9 (D4), U9.16 (Q4)
/D_{5}: P1.27 (D5), U7.40 (D5), U8.10 (D5), U9.17 (Q5)
/D_{6}: P1.28 (D6), U7.42 (D6), U8.11 (D6), U9.18 (Q6)
/D_{7}: P1.29 (D7), U7.44 (D7), U8.12 (D7), U9.19 (Q7)
/PHI: P1.2 (CLK), U10.6
/RA_{14}: U7.3 (A13), U8.15 (RA14)
/RA_{15}: U7.2 (A14), U8.16 (RA15)
/RA_{16}: U7.1 (A15), U8.17 (RA16)
/RA_{17}: U7.48 (A16), U8.18 (RA17)
/RA_{18}: U7.17 (A17), U8.19 (RA18)
/RA_{19}: U7.16 (A18), U8.20 (RA19)
/RA_{20}: U7.9 (A19), U8.21 (RA20)
/RA_{21}: U8.22 (RA21)
/RA_{22}: U8.25 (RA22)
/~CS: P1.5 (~CS), U8.31 (~CS), U10.3
/~CS_{OR}: R17.1, U9.20 (~CS), U10.4
/~CS_{RAM}: U8.14 (~RAM_CS), U10.1
/~RD: P1.4 (~RD), U7.28 (~OE), U9.22 (~OE)
/~RST: P1.30 (~RST), U8.13 (~RESET)
/~WR: P1.3 (~WR), U7.11 (~WE), U8.30 (~WR), U9.27 (~WE)
GND: C19.2, C20.2, C21.2, C22.2, P1.32 (GND), U7.27 (GND), U7.46 (GND), U7.47 (~BYTE), U8.4 (GND4), U8.23 (GND23), U9.14 (GND), U10.2 (GND)
VCC: C19.1, C20.1, C21.1, C22.1, P1.1 (VCC), R17.2, U7.12 (~RP), U7.37 (VCC), U8.24 (VCC), U9.28 (VCC), U10.5 (VCC)

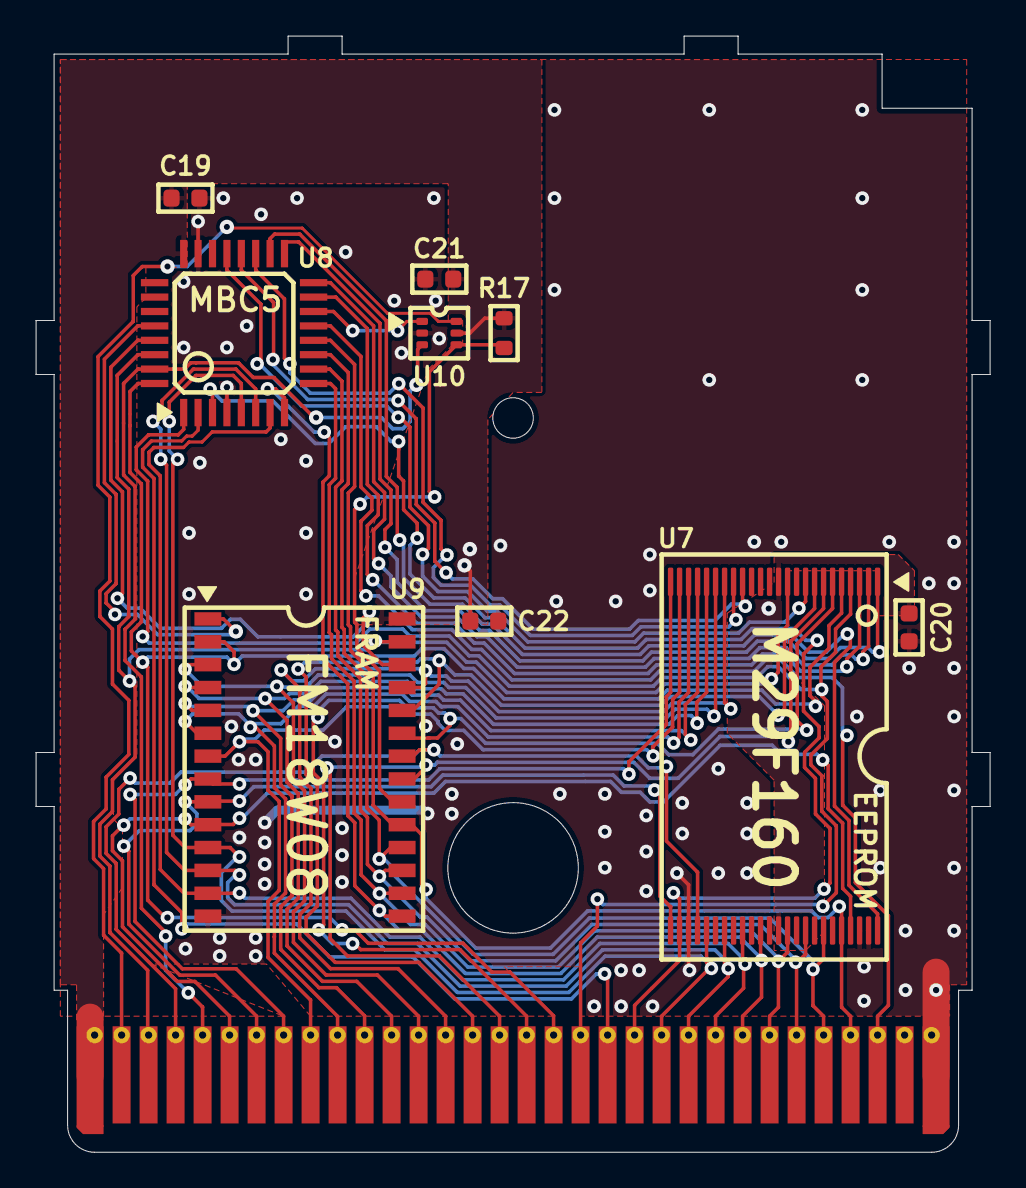
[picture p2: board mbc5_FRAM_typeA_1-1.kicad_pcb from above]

Board: 2 copper layers, 53.0 x 62.0 mm, 10 parts (0 on the bottom side), 42 nets.
